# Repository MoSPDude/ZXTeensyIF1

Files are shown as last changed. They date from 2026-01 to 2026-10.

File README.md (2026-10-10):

# ZXTeensyIF1

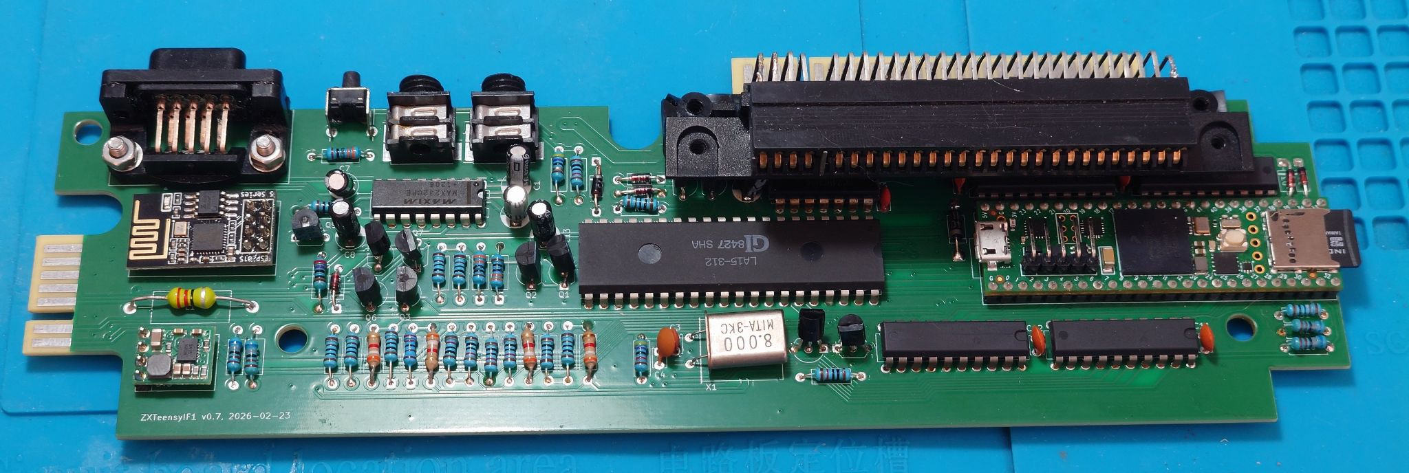
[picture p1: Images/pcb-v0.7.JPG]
Working PCB


A Teensy 4.1 powered DivMMC and ZX Interface 1 clone for the ZX Spectrum 48K/128K/+2 (Grey) machines,

* ZX Interface 1
    * Requires the 9V and 5V power rails
    * Uses a MAX232 for the RS232 level shifting, so no +12V or -12V required
    * Supports 16KB shadow soft ROM
        * eg. Ian Collier's modified Interface 1 ROM from https://ftp.nvg.ntnu.no/pub/sinclair/roms/imc-i1rom.zip
            * The [imc-i1.rom](Extras/imc-i1.rom) here contains a copy with the "Parallel Printer" modification disabled
* DivMMC with 512KB RAM
    * Supports accessing the main SD card, HDF and IMG images
    * Supports DivMMC AllRAM extension with write lock, automap disable and alternate MAPRAM page
        * https://github.com/mprato/DivMMC/blob/master/docs/Divmmc_allram_manual.txt
    * Large images over FAT32 file limit can be split into multiple files
        * eg. esximage.hdf, esximage.001, up to esximage.999
        * The maximum SD card image size is ~2TB
    * If you use images from https://esxdos.zxfiles.net/ - remember to hex edit "DMA=1" to "DMA=0"
* Multiface 128 emulation
    * NMI button and soft ROM
* ZX Interface 2 ROM cartridge emulation
    * It does not emulate the Joystick ports
* ZXC2 and ZXC3 with Flash ROM cartridge emulation
    * Implements ZXC2 ROM banking
    * Implements ZXC3 ROM banking with 128KB Flash ROM
    * Implements SPECTRA shadow ROM support
        * The ROM file needs to be named as "SPECTRA_\*.bin"
* Dandanator Mini with Flash ROM cartridge emulation
    * Implements slow pulsed banking, and fast command banking
    * Can load individual MLD files, or full 512KB generated ROM images
* ESP-01S module via TX8/RX8
    * Requires the 9V power rail for the 3.3V regulator
    * Available on ports 0x143B (5179) for RX and 0x133B (4923) for TX
    * https://www.specnext.com/the-next-on-the-network/
* USB mouse and gamepad Kempston interface
    * Not wired to the board - use a small lead that exits the case
    * eg. StarTech.com "6in USB 2.0 Cable - USB A Female to USB Motherboard 4 Pin Header F/F"
* RTC module from the Teensy
    * Accessed as a RTC-72421 on ports 0x7X3B
        * The time is only read or written when register 0xD sets HOLD to 1
    * Uses a minor bugfixed RTC.SYS from https://velesoft.speccy.cz/zx/rtcmodule/index.htm
        * Patched byte 6 from 0x0D to 0x7D
    * Not wired to the board - attach a coin cell battery to VBAT
        * See https://www.pjrc.com/store/teensy41.html#timing
* Single speed TZX and TAP playback
    * Playback locks the keyboard, as it overdrives the ULA
    * TAP loading is better done via the DivMMC
* Spectrum +3 uPD765a FDC emulation
    * Integrated lib765 v0.4.2 with additional bug fixes for "EXTENDED" disk loading
    * Requires Spectrum +2A/+3 soft ROM support (see below), or other compatible DOS
* Prism VTX5000 over ESP-01S
    * Creates a serial tunnel over WiFi to given URL
    * Default URL is '"glasstty.com",6502' - https://glasstty.com/telstar/
* Spectrum +3 and ZX LPRINT III Centronics printer
    * Writes output into a timestamped "printer-YYYYMMDD-HHMMSS.txt" file on SD card, adding a numeric suffix if that file already exists
* Soft ROM emulation
    * Override the internal Spectrum ROM with ROMs from SD card
    * Supports 16KB (Spectrum 48K), 32KB (Spectrum 128K/+2 (Grey)) and 64KB (Spectrum +2A/+3) ROMs
        * The +2A/+3 soft ROM support requires port decoding changes (see below)
    * Provides the peripheral ROMs
* Menu ROM derived from TomDDGs ZXPicoIF2Lite ROMExplorer
* Z80 snapshot loading from TomDDGs ZXPicoIF2Lite
    * Integrated "z80torom" for loading 'z80' and 'sna' files
* Save and restore states
    * Uses the Z80 snapshot loader to restore state on power-on
    * Hold the button to disable the power-on restore
* MDR microdrive loading with Paul Farrows SPECTRA Microdrive Emulator
    * http://www.fruitcake.plus.com/Sinclair/Interface2/Cartridges/Interface2_RC_New_Microdrive_Emulator.htm
    * Supports MDR images with up to 90KB of data
* Small WebDAV class 1 HTTP server for WiFi file access over ESP-01S
    * Accepts five clients, with SD card requests processed one at a time
    * Use WinSCP to send files, or HTTP PUT to send files eg. "curl -T FILENAME.ROM http://192.168.0.254/FILENAME.ROM"
        * Includes a simple LOCK/UNLOCK compatibility shim for Windows 11 support
    * Use web browser to list files, and download
* Nihirash's Network Manager for WiFi configuration
    * Small bugfix to clear the BASIC keypress on load
* Velesoft's RTC_SETUP for RTC configuration
    * Minor tweaks to preset the RTC port
* External ROM support
    * ZX Interface 1 edge connector supports other ROM based hardware
    * eg. Retroleum SMART card, real ZX Interface 2 hardware etc.

The ZX Interface 1 v2 ROM is included in compiled firmware, and as noted on other
sources "Amstrad have kindly given their permission for the redistribution
of their copyrighted material but retain that copyright"

The ZXTEENSY directory contains the peripheral ROM images - the exact redistribution
status of these is unknown, but they have been gathered from sources from the Internet,
and provided for convenience and safe-keeping.

This is a project that I started with a view of wanting a DivMMC clone that works with a
ZX Interface 1 attached to my ZX Max 128 - as I own a ZX Microdrive as well as a ZXPicoMD
(https://github.com/TomDDG/ZXPicoMD) ... and didn't want to keep disconnecting the ZX
Interface 1.

> [!WARNING]
> I created this for myself, and it is distributed in the hope that it will be useful,
> but WITHOUT ANY WARRANTY; without even the implied warranty of MERCHANTABILITY or
> FITNESS FOR A PARTICULAR PURPOSE.
>
> I take ZERO responsibility if it damages your hardware!

## Credits

Full credits to the following projects - this project gathers and integrates from
many various sources.

It borrows content, ideas and inspiration from,

* http://www.pjrc.com/teensy/
    * Teensyduino Core and SdFat libraries - provides all the Teensy 4.1 functionality
    * Reused parts of code for the RTC, SDHC and UART drivers
* https://github.com/SensoriumEmbedded/TeensyROM
    * Initial code and parts for the Teensy 4.1 firmware
* https://github.com/TomDDG/ZXPicoIF2Lite
    * ROM menu source code, Z80 snapshot loader, and the idea of a soft ROM
* http://www.fruitcake.plus.com/Sinclair/Interface2/Cartridges/Interface2_RC_Cartridges.htm
    * ZXC2 and ZXC3 banking, and Microdrive Emulator
* http://www.dandare.es/Proyectos_Dandare/ZX_Dandanator%21_Mini_EN.html
    * Dandantor Mini slow banking from PIC source code
    * Also, https://github.com/chernandezba/zesarux/tree/main/src/storage for fast banking
* https://github.com/nihirash/netman-zx
    * WiFi Network Manager for the ESP-01S
* https://velesoft.speccy.cz/zx/rtcmodule/index.htm
    * RTC_SETUP for the RTC module
    * RTC.SYS for EsxDOS
* https://www.seasip.info/Unix/LibDsk/
    * lib765 FDC controller library
* https://github.com/joepasquariello/FlasherX
    * Teensy 4.x OTA upgrade library
* https://github.com/liveboxandy/ZX-Interface-1-Recreated
    * Re-used the ZX Interface 1 board layout and schematic
* https://github.com/ZXSpectrumVault/rom-disassemblies
    * ZX Interface 1 v2 ROM disassembly
* https://spectrumcomputing.co.uk/pub/sinclair/technical-docs/ZXInterface1_Schematics.gif
    * ZX Interface 1 schematic
* https://spectrumcomputing.co.uk/pub/sinclair/technical-docs/PrismVTX5000Modem_Schematics-Interface.bmp
    * Prism VTX5000 schematic
* https://zxpress.ru/chapters_images/periferiya/periferiya-33.png
    * ZX LPRINT III schematic
* https://divide.speccy.cz/files/pgm_model.txt
    * DivIDE programming model
* https://www.thingiverse.com/thing:6500064
    * Also from TomDDG, a replacement ZX Interface 1 case

Without the above projects, this would not have been possible!

## Construction

[Construction details are here](PCB/README.md)

## SD Card Setup

* ZXTEENSY/
    * CONFIGS/
        * \<NAME\>.CFG (Saved configurations that appear as "NAME" in the Menu ROM for quick selection)
    * STATE/\<SLOT\>/ (Save slots 0-14; slot 15 is reserved)
        * STATE.Z80 (Z80 v3 snapshot for the save state)
        * SCREEN.SCR (6912-byte active Spectrum screen for load preview)
        * (Additional saved state files for the save slot)
    * MENU.ROM
    * MF128.ROM (MD5SUM: ca8c9d97c8aedd718d1081fad2e3af8d)
    * GENIE128.ROM (MD5SUM: b942f2e658d15da9747791a15a9a110d)
        * Genie 128K disassembler Multiface 128 RAM image
    * ESXMMC.BIN (MD5SUM: fa50b0258e52b8d72bd83cc2fb6e1013)
    * SPECTRA_IF1_ED2_ME_ROM_Formatted.bin (MD5SUM: 052ad91ee822604960e8ca8d32a3ddb9)
    * IF1.ROM (Optional)
    * VTX.ROM (MD5SUM: 12a62cb7ea7383f109c2711dfca99f5e)
    * LPRINT32.ROM (MD5SUM: e85f4ccb4cc80aaa81cceffb3e064bf7)
    * netman.z80 (WiFi Network Manager snapshot)
    * rtc_setup.z80 (RTC Setup snapshot)
    * ZXTEENSY.CFG (Current configuration from Menu ROM)
* ROMS/
    * (ZX Spectrum ROMs ending ".rom")
    * (ZXC2 ROMs ending ".bin")
    * (Other ROM files)
* (Other ESXDOS files)
* SYS/
    * [RTC.SYS](Extras/RTC.SYS) (Optional, for RTC access)
    * (Other ESXDOS files)
* ZXTEENSY.HEX (Optional, firmware update)

## Using the Menu ROM

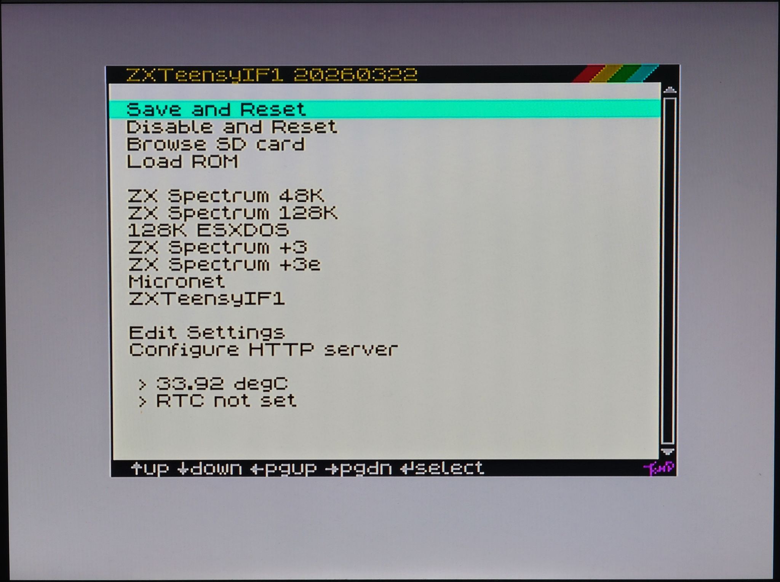
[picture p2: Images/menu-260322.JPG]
Menu 20260322


To load the Menu ROM, either,

* Use "Boot into Menu" to load on initial power on
* or, Hold the button, and Reset
* or, Hold Reset for longer than 5 seconds

Inside the Menu ROM you can,

* Restart with either the ZXTeensyIF1 enabled or disabled
    * Pressing Reset will also reset with the ZXTeensyIF1 enabled
* Browse the SD card to select files to load, or mount
    * Selecting known file extensions will either load or ask to mount
    * Selecting unknown file extensions will ask for an action
    * From the in-game browser, select a POK file and tick one or more trainers
      before selecting "Apply selected trainers"
* Browse the system Soft ROMs in the "ROMS/" directory to load, or set as Soft ROM
    * Double selecting a system Soft ROM will immediately reset into it
* Select a saved configuration to load
    * Double selecting a saved configuration will immediately reset into it
* Edit the configuration
    * Enable or disable the peripherals
    * Eject mounted disks by selecting them
    * Set to fetch time over the WiFI, and set the timezone
    * Load the RTC Setup or WiFi Network Manager snapshots
* Start or stop the HTTP server to transfer files over WiFi

To firmware update, place the ZXTEENSY.HEX file on the root of the SD card and
select the option from the Menu ROM - then wait for the Spectrum to reset
(!! It will take a minute !!).

In "Load ROMS", from the "ROMS/" directory,

| File extension | File type |
|---|---|
| .rom | System Soft ROM |
| .bin | ZXC2 cartridge |
| Other | ZX Interface 2 cartridge |

In "Browse SD card", in other directories,

| File extension | File type |
|---|---|
| .rom, .bin | ROM cartridge, or RAM image |
| .z80, .sna | Z80 snapshot |
| .hdf, .img | DivMMC SD card |
| .dsk | Spectrum +3 disk |
| .mdr | ZX Microdrive cartridge |
| .tap, .tzx | Audio cassette |
| .pok | POK trainers (in-game browser only) |
| Other | The menu will ask for an action |

POK trainers are applied by saving a temporary state to reserved slot 15,
patching the selected RAM banks, and immediately restoring that state. POK
trainers that require a prompted value (`256`) are not supported and cannot be
enabled.

### Preparing the SD Card

ESXDOS has trouble loading if it is not "early" on the SD card,

* Format the SD card with FAT32
* Extract ESXDOS on computer, and transfer all directories and ESXMMC.BIN to the SD card
* Transfer the "/ZXTEENSY" directory, with ROMs and CONFIGS
* Create system "/ROMS" directory, and add other ROMs
* Add any other files

#### Fun stuff !!

The https://esxdos.zxfiles.net/ site has a HDF image that can be split using the script
in the tools folder, to use as an SD card image.

 * You will just need to hex edit part of the image file to change the setting "DMA=1" to "DMA=0" !!
 * You can browse the image with 7-Zip to extract the "GAMES.ROM" folder for access to the ROM games

The [MOONR.zip](Extras/MOONR.zip) is a compiled version of Moon Rabbit v1.6 from
https://github.com/nihirash/moon-rabbit-zx with MB03+ serial for the WiFi, but
with the regular Spectrum screen and without the proxy ("-DMB03 -DZXSCR").

The [imc-i1.rom](Extras/imc-i1.rom) is Ian Collier's modified Interface 1 ROM -
place it as "ZXTEENSY/IF1.ROM" to use instead of the internal compiled v2 ROM.

Z80 BBC BASIC for the ZX Spectrum can be downloaded from https://mdfs.net/Software/Spectrum/BBCBasic/ .
Use the 32K combined BBC BASIC and ZX BASIC ROM - placing it in the ROMS folder, and
selecting it as the system ROM.

## Building the firmware

* Setup the Arduino IDE 2.3.6 for the Teensy 4.1
    * "Teensy (for Arduino IDE 2.0.4 or later)" v1.60.0
* Open ZXTeensyIF1\ZXTeensyIF1.ino
* Set Board to Teensy 4.1
* Set Optimize to "Smallest Code with LTO"
* Set CPU Speed to "720 MHz (overclock)"
* Verify and Upload

## Prism VTX5000 support

The VTX5000 over ESP-01S uses the ESP8266 in UART-WiFi passthrough mode after establishing
a connection to a URL over TCP. If the VTX.ROM is provided, then it will load after reset.
The default URL is the TELSTAR Viewdata service at https://glasstty.com/telstar/ .

To access TELSTAR,
 * Press CAPS SHIFT + ENTER to open the menu
 * Press 0 to "Log ON or OFF"
 * Press 1 for "Manual Log ON"
 * Enter the ID "\*\*\*\*\*\*\*\*\*\*" ie. 10 asterixes
 * Read the welcome message, and press ENTER as the "#" key

To navigate, either press numbers to select items, or enter pages in the form of "*800#" :-
 * SYMBOL SHIFT is the "*" key
 * ENTER is the "#" key

## WebDAV class 1 support

The HTTP server accepts five connections. Requests are processed one at a time because the
ESP-01S UART and SD card are shared; an inactive connection remains buffered by the ESP-01S.

Windows 11 sends LOCK and UNLOCK commands when copying files to the server, though not
supported in WebDAV class 1. The server just acknowledges the exclusive file locks, creates
the empty target required by a LOCK on a new path, and accepts refresh and unlock requests -
purely as a compatibility shim. An interrupted transfer can leave its empty target file behind.

WinSCP seems to work fine - you may need to change the preferences to ensure only
a single upload connection.

OpenAI Codex helped to provide the additional WebDAV class 1 implementation over
just the basic HTTP PUT and GET that I'd implemented.

## +2A/+3 soft ROM on Spectrum 128K/+2 (Grey) machines

Spectrum 128K, +2 (Grey) and similar machines (eg. ZX Max 128 Issue 3) require a modification to
support the +2A/+3 soft ROM.

Without it, accesses to the Secondary Memory Control register (0x1FFD) also affect the original
Memory Control register (0x7FFD) due to the partial decoding. (More info at
https://worldofspectrum.org/faq/reference/128kreference.htm)

### Spectrum 128K/+2 (Grey) Memory Control port decoding

The BANK decoding is performed by a PAL10H8 chip, which can be swapped for a GAL16V8 to apply
the "Unrainer/IN 7FFD" fix - see https://spectrumforeveryone.com/technical/applying-the-unrainerin-7ffd-fix-to-128grey-2-machines/ and
Velesoft https://velesoft.speccy.cz/zx/umbrella/umbrella.htm for the original article and files.

Unrainer fixed GAL16V8s with socket and wire can be bought from the Retroleum shop at
https://retroleum.co.uk/.

But, by adding a "BANK = ... & ZA14" term, then the GAL will support the decoding
required for the +2A/+3 soft ROM.

I've placed the updated files in the GAL folder.

* Remove IC29 (Spectrum 128K) / IC7 (Grey +2) - and replace with a socket
    * *Take care of the orientation of the socket!* (The Grey +2 has it pointing downwards)
* On the underside, add a wire from CPU pin 28 to the GAL socket pin 11
* Program the GAL16V8 with GALNEW2A.JED, and fit into socket
    * Again, taking care with the orientation!

### ZX Max 128 Issue 3 Memory Control port decoding

The modification is shown at
https://github.com/DonSuperfo/ZX-Max-128/blob/main/Issue%203/Modify%20for%20%2B3%20ROM.pdf,

* Replace R12 with a 1N4148 diode, with cathode to U9 pin 9
    * So it is the same orientation as D1 that is next to it
* Add a 1N4148 diode from U6 pin 12 to the cathode of the new diode in place of R12
    * This connects "nA14"
* Add a 10K resistor from ground (eg. U9 pin 8) to the cathode of the new diode in place of R12
    * This is the replacement position for R12

## 3rd party Xbox One USB gamepads

You will need to find and add the USB PID:VID code for the controller to the USBHost_t36
library.

In the case of my "8BitDo M30 Wired Controller for Xbox One", under Windows 11
Device Manager, it was the "Xbox Peripherals > Xbox Gaming Device" *NOT* the
(virtual) HID device. Right click the device, select Properties, then Details and
select "Hardware IDs" to find it listed as "USB\VID_2DC8&PID_200A&..."

Once found, add the USB PID:VID code to %LOCALAPPDATA%\Arduino15\packages\teensy\hardware\avr\1.60.0\libraries\USBHost_t36\joystick.cpp,
under JoystickController::pid_vid_mapping ,

* 8BitDo M30 Wired Controller for Xbox One :- \{ 0x2dc8, 0x200a, XBOXONE, false \}

## ROM paging and banking

ROMs are paged in a priority order - if more than one ROM is paged, the highest active entry wins.
When that ROM pages out, it falls back to the next highest active entry. The base
Spectrum ROMs are mutually exclusive, and selected by the 128K/+2A/+3 Memory Control
registers - while add-on ROMs can sit above them until they are paged out.

The following ROMs are provided by the Teensy, listed in priority order,

| Peripheral / ROM | Pages in from | Pages out from | Banking notes |
| --- | --- | --- | --- |
| Spectrum ROM 0 | On reset, or I/O port 0x7FFD bit 4 = 0, and I/O port 0x1FFD bit 2 = 0 | Replaced by another Spectrum ROM | 48K BASIC ROM, or 128K/+2 Editor ROM slot |
| Spectrum ROM 1 | I/O port 0x7FFD bit 4 = 1, and I/O port 0x1FFD bit 2 = 0 | Replaced by another Spectrum ROM | 128K/+2 BASIC ROM, or +2A/+3 Syntax ROM slot |
| Spectrum ROM 2 | I/O port 0x7FFD bit 4 = 0, and I/O port 0x1FFD bit 2 = 1 | Replaced by another Spectrum ROM | +2A/+3 +3DOS ROM slot |
| Spectrum ROM 3 | I/O port 0x7FFD bit 4 = 1, and I/O port 0x1FFD bit 2 = 1 | Replaced by another Spectrum ROM | +2A/+3 BASIC ROM slot |
| Interface 1 | Post-M1 access to address 0x0008 or 0x1708 from Spectrum ROM 0, 1 or 3, when Interface 1 is enabled and DivMMC is not | Post-M1 access to address 0x0700 | Emulates Interface 1 ROM paging while the Teensy inhibits the physical Interface 1 ULA I/O decode when DivMMC is active. |
| Multiface 128 | Multiface NMI path at address 0x0066/0x0067, or read from I/O port 0xXXBF | Read from I/O port 0xXX3F; write to I/O port 0xXX3F also disables Multiface mode | Higher priority than Interface 1, so Interface 1 may be marked paged underneath it and then become visible after Multiface pages out. |
| DivMMC | M1 access to addresses 0x3Dxx, post-M1 access to addresses 0x0000, 0x0008, 0x0038, 0x04C6 or 0x0562 from Spectrum ROM 0, 1 or 3; DivMMC NMI at address 0x0066; I/O port 0xXXE3 with CONMEM/automap active; or AllRAM enabled | Post-M1 access to addresses 0x1FF8-0x1FFF unless MAPRAM or AllRAM is active; or I/O port 0xXXE3 when CONMEM, automap and AllRAM are clear | I/O port 0xXXE3 also selects the DivMMC RAM bank. Bit 7 is CONMEM, bit 6 latches MAPRAM, and the low bits select internal or extended RAM. MAPRAM serves RAM bank 3 (or the alternate AllRAM page) instead of the ROM when CONMEM is clear. |
| LPRINT III | Read from I/O port 0xXXFB | Read from I/O port 0xXX7B | Printer data/strobe writes use I/O ports 0xXX7B and 0xXXFB; ROM paging itself is read-port driven. |
| VTX5000 modem | VTX5000 register write to I/O port 0xXXFF with bit 5 clear | VTX5000 register write to I/O port 0xXXFF with bit 5 set | The first register write after reset is ignored. |
| ZXC2/ZXC3 cartridge | ZXC2/ZXC3 address-banking access in addresses 0x3FC0-0x3FFF, or post-M1 access to address 0x0008/0x1708 when used as Shadow ROM | ZXC2/ZXC3 address-banking access in addresses 0x3FC0-0x3FFF, or post-M1 access to address 0x0700 when used as Shadow ROM | For ZXC2, address bits 0-3 select the 16KB bank and bit 4 pages in/out. ZXC3 uses bits 0-2 for the bank and bit 3 to enter flash-write handling. Bit 5 locks further ZXC2/ZXC3 paging. |
| Dandanator/MLD cartridge | Dandanator/MLD slow-pulse or fast command bank select | Dandanator/MLD page-out command | Commands 1-32 select slots, command 33 pages out, command 34 pages out and locks, and command 40 performs the fast bank/control command. |
| Snapshot/state loader | Snapshot/state loader start | Access to address 0x3FFF advances loader banks; the final access pages out | Used for generated snapshot/state loader ROMs. |
| Menu ROM | Menu NMI target at address 0x0066, from any current ROM | Post-M1 access to address 0x003B | Highest priority ROM. I/O port 0xXXBF selects the active menu RAM page, and I/O port 0xXXEB is used for menu commands and selections. |

## I/O port mapping

The following ports are decoded by the Teensy,

| Port | R/W | Function | Comments |
| ---- | --- | --- | --- |
| 0xXX1F | R | Kempston joystick | |
| 0x0F3B | W | DivMMC AllRAM control register | |
| 0x133B | R | UART status | |
| 0x133B | W | UART TX data | |
| 0x143B | R | UART RX data | |
| 0x143B | W | UART baud register | |
| 0x7N3B | R/W | DivMMC RTC registers 0 - 15 | N is the register address |
| 0xXX3F | R | Multiface 128 page out | Returns bit 7 as the Current Screen |
| 0xXX3F | W | Multiface 128 disable | |
| 0xXX7B | R | LPRINT III page out | Returns status |
| 0xXX7B | W | LPRINT III data with strobe | |
| 0xXX7F | R/W | VTX5000 data | |
| 0xXXBF | R | Multiface 128 page in | Returns bit 7 as the Current Screen |
| 0xXXBF | W | Multiface 128 NMI clear | Menu ROM RAM banking |
| 0xFADF | R | Kempston mouse buttons | |
| 0xFBDF | R | Kempston mouse X axis | |
| 0xFFDF | R | Kempston mouse Y axis | |
| 0xXXE3 | W | DivMMC control register | |
| 0xXXE7 | W | DivMMC SPI select | |
| 0xXXEB | R/W | DivMMC SPI data | Menu ROM read command, write selected option |
| 0xXXFB | R | LPRINT III page in | Returns status |
| 0xXXFB | W | LPRINT III data, clear strobe | |
| 0x0FFD | R | +3 Centronics busy status | |
| 0x0FFD (0b0000XXXX_XXXXXX0X) | W | +3 Centronics data | |
| 0x1FFD (0b0001XXXX_XXXXXX0X) | W | +2A / +3 Secondary Memory Control | ROM paging, +3 FDC motor and +3 Centronics strobe |
| 0x2FFD | R | +3 FDC status register | |
| 0x3FFD | R | +3 FDC data | |
| 0x3FFD (0b0011XXXX_XXXXXX0X) | W | +3 FDC data | |
| 0x7FFD (0b01XXXXXX_XXXXXX0X) | W | 128K Memory Control | Current Screen, and ROM paging |
| 0xXXFE | R | Spectrum ULA | Drives EAR input for tape |
| 0xXXFF | R/W | VTX5000 register | Ignore first write access, controls ROM paging |

The following ports are decoded by the Interface 1 ULA when not inhibited by the Teensy,

| Port | R/W | Function | Comments |
| ---- | --- | --- | --- |
| 0xXXE7 (0bXXX00XXX) | R/W | Interface 1 microdrive data | Halts Z80 on read |
| 0xXXEF (0bXXX01XXX) | R/W | Interface 1 control register | |
| 0xXXF7 (0bXXX10XXX) | R/W | Interface 1 RS232/network data | |

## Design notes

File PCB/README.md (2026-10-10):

# ZXTeensyIF1 Construction

## Loading the KiCad project

The PCB folder contains a KiCad 9.0.2 project, based on liveboxandy "ZX Interface 1 Recreated" KiCad
7 project. Without that project, I'd have had to spend considerable time getting the board outline
correct, and aligning the sockets etc.

It uses,

* https://github.com/XenGi/teensy_library as teensy_library-master
* https://github.com/XenGi/teensy.pretty as teensy.pretty-master
    * Set XGENGI_TEENSY_LIBRARY path in Symbol Libraries etc.
* https://github.com/sparkfun/SparkFun-KiCad-Libraries
    * Set SPARKFUN_KICAD_LIBRARY path in Symbol Libraries etc.
* https://github.com/nosuz/kicad-symbols-footprints
    * Place as ./nosuz-kicad-symbols-footprints in the project directory

Freerouting (https://github.com/freerouting/freerouting) was used to perform the initial routing,
especially with getting the address and data lines out to the level shifters and the Interface 1
ULA.

## Bill of Materials

| Reference | Qty | Value | Comments |
| --- | --- | --- | --- |
| C1, C2, C7, C8 | 4 | 1uF | Use 0.1uF if U8 is MAX232A, or 0.33uF if MAX3232 |
| C3 | 1 | 100pF | |
| C4 | 1 | 22pF | |
| C5 | 1 | 47nF | |
| C6, C13 | 2 | 47uF 16V | |
| C9, C10, C11, C12 | 4 | 100nF | |
| D1, D2, D3, D9, D11 | 5 | 1N4148 | |
| D4 | 1 | 1N4001 | or 1N400X equivalent |
| D8 | 1 | BZX79CV4V3 | or ZPD4V3 equivalent |
| J1 | 1 | ESP-01S | Optional, for WiFi |
| J3 | 1 | Polou D24V5F3 | Optional, fit if ESP-01S is fitted |
| L1 | 1 | 22uH 0.41A | |
| Q1, Q2 | 2 | BC213C | |
| Q3, Q6, Q9 | 3 | BC184C | |
| Q4, Q5, Q7, Q8 | 4 | PN2222A | |
| Q10, Q11 | 2 | ZTX313 | |
| R1, R3, R5, R11, R12, R14, R24, R25, R31 | 9 | 1K0 | |
| R2, R10, R17, R18 | 4 | 6K8 | |
| R4, R6, R8, R13 | 4 | 3K9 | |
| R7 | 1 | 47R | |
| R9, R16, R21, R26, R27, R33, R36 | 7 | 10K | |
| R15 | 1 | 2K2 | |
| R22, R23, R34 | 3 | 330R | |
| R30 | 1 | 270R | |
| R35 | 1 | 47K | |
| SK1 | 1 | DE9_Receptacle | |
| SK2, SK3 | 2 | 3.5mm Mono Switched Socket | with break contact eg. Cliff CL1384 |
| SK5 | 1 | ZX Spectrum edge connector | Can be difficult - see notes |
| SW1 | 1 | PTH_RA_h7.5mm | 6 x 6mm x 8mm Right Angle |
| U1 | 1 | LA15-302 | ZX Interface 1 ULA - can be LA15-312 or vLA1 |
| U2 | 1 | Teensy4.1 | Teensy 4.1 No Ethernet |
| U3, U5, U6, U7 | 4 | SN74LVC245AN | |
| U4 | 1 | 74HCU04 | |
| U8 | 1 | MAX232 | Alternative is MAX232A or MAX3232 |
| X1 | 1 | 8Mhz crystal | |

## Notes

In my build, the 74HCU04, BZX79CV4V3, 8 MHz crystal, 3K9 resistors, inductor
and all connectors came from a donor ZX Interface 1 board. The ULA was a LA15-312
that I had bought to fix the donor originally, before I had the idea to create
this. Removing the ZX Interface 1 edge connector that goes to the ZX Spectrum was
an immense pain - even with gentle heat, I managed to deform and melt the plastic
riser block... it was as though it was glued to the board as well as screwed.

But for my second board, having found another donor that had a ULA that melted the
case, simply removing the screws holding the edge connector riser and de-soldering
was enough - it was removed very easily! The ULA for this board is a replacement
vLA1, that worked after some firmware fixes. Only the connectors and BZX79CV4V3
had been re-used from this donor board.

## Hardware revisions

* v0.7b PCB
    * *NOT MANUFACTURED*
    * Changed C13 to 47uF
        * The Teensy was not always resetting correctly after power on, so increased this
    * Moved C6 slightly
        * The ZX Spectrum edge connector plastic riser block had a support that just caught the top of it!
        * Hopefully, this slight adjustment will solve that
* v0.7 PCB prototype
    * PCBs have been returned from PCBWay
    * Moved the ROMCS and DataDir output to pins 36 and 37, to free up pins 34 and 35
    * Added an ESP-01S header, and header for 3.3V regulator (eg. Pololu D24V5F3)
        * The ESP-01S can take over 300mA, so requires a separate regulator
        * The Pololu D24V5F3 is a 3.3V 500mA regulator module, available from The Pi Hut
        * I had to re-organise the left side of the board to make room
    * Connected RX8 pin 34 and TX8 pin 35, to the ESP-01S header
* v0.2 PCB prototype
    * First PCBs made, and tested
        * Microdrive, RS232, ZX Net and nROMCS on external edge connector working
        * Firmware updated for new pin layout - soft ROM all working
    * Need to revise some footprints
    * The PCBs had silkscreen that stated v0.1
* v0.1 veroboard prototype (not uploaded)
    * Prototype to test the initial idea
    * Teensy 4.1 and level shifters on Veroboard
        * Soft ROM and Multiface 128 behaviour working
    * Modded ZX Interface 1 to add "nIORQ inhibit" (see below)

## DivMMC and ZX Interface 1 support

Technically, the DivMMC and ZX Interface 1 cannot be active simultaneously. The DivMMC ports and
ZX Interface 1 I/O ports clash directly. (More info at below)

To overcome this, the Teensy drives the nIORQ of the Interface 1 ULA high when the DivMMC is
active. Also, only A3 and A4 have been wired to the Interface 1 ULA, as required for the port
decoding - which helped with the PCB routing. The Teensy provides all the ROM facilities for
the Interface 1 behaviour.

## Updating the ESP-01S

The ESP-01S needs to be running the Non-OS AT firmware that can be downloaded from
https://github.com/espressif/ESP8266_NONOS_SDK .

The current version is SDK v3.0.6 with AT version 1.7.6.0,
```
AT version:1.7.6.0(Jan 24 2022 08:56:02)
SDK version:3.0.6-dev(072755c)
compile time:Jun 17 2024 07:38:00
Bin version(Wroom 02):1.7.6
```

The ZXTeensyIF1 cannot update the firmware, so it needs to be done with a suitable
connection to a computer - such as https://thepihut.com/products/esp-flasher and
the VSCode Serial Monitor.

To find your current version, issue the command "AT+GWR" at baud rate 115200,
1 stop bit, no parity, DTR set, RTS set, with CRLF line endings.

I used esptool-v4.8.1-win64 and the following command to flash, with my USB serial
adapter on COM3,
```
./esptool.exe -p COM3 write_flash --flash_size 1MB 0x0 boot_v1.7.bin 0x01000 user1.1024.new.2.bin 0xfb000 blank.bin 0xfc000 esp_init_data_default_v08.bin 0xfe000 blank.bin 0x7e000 blank.bin
```

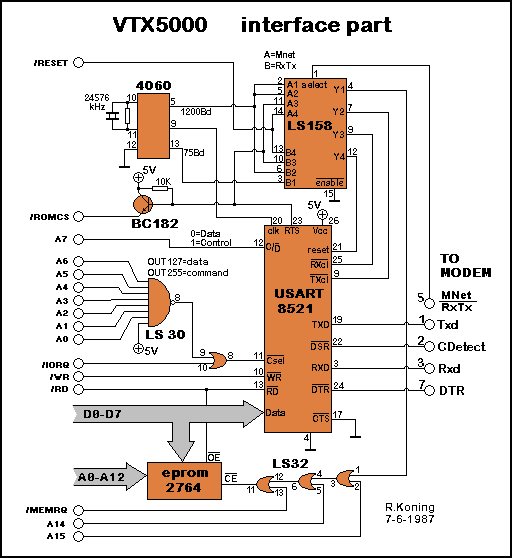
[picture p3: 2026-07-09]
Images/PrismVTX5000Modem_Schematics-Interface.bmp

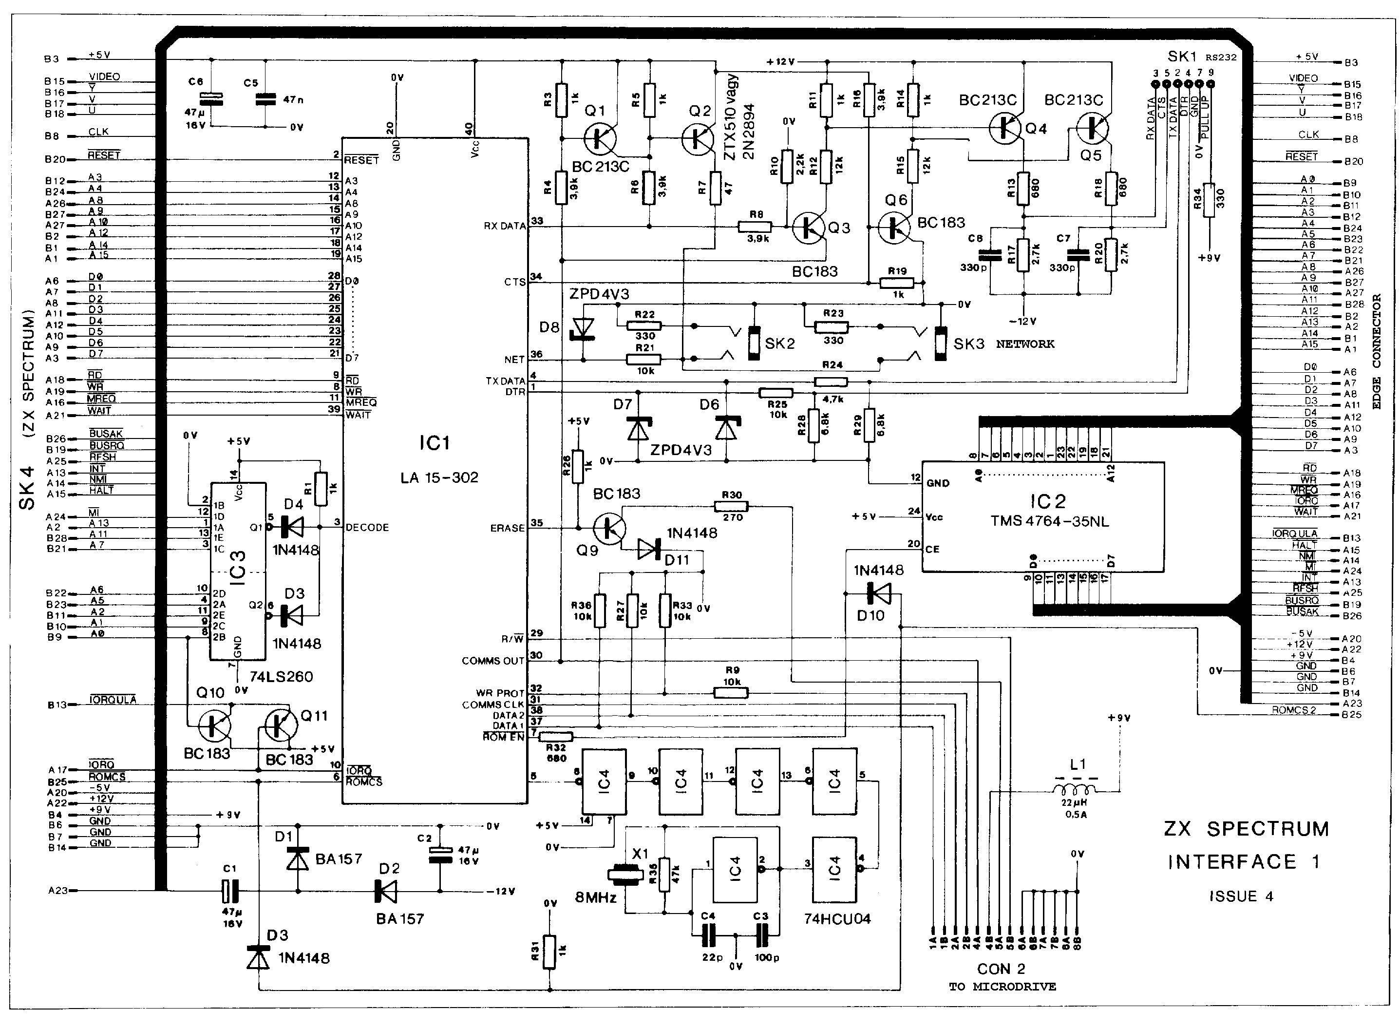
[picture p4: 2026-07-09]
Images/ZXInterface1_Schematics.gif

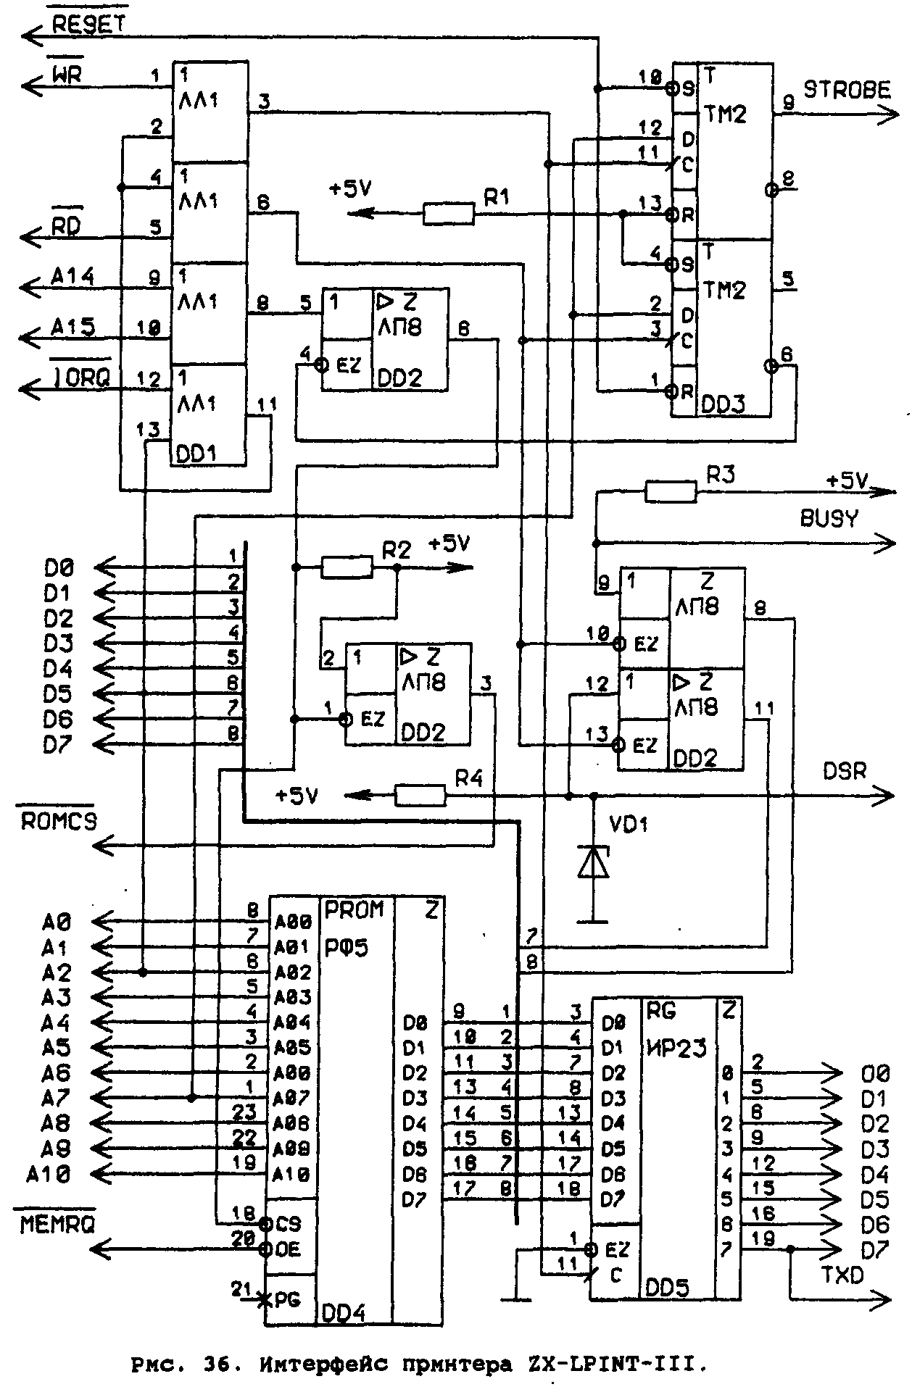
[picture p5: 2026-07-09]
Images/periferiya-33.png

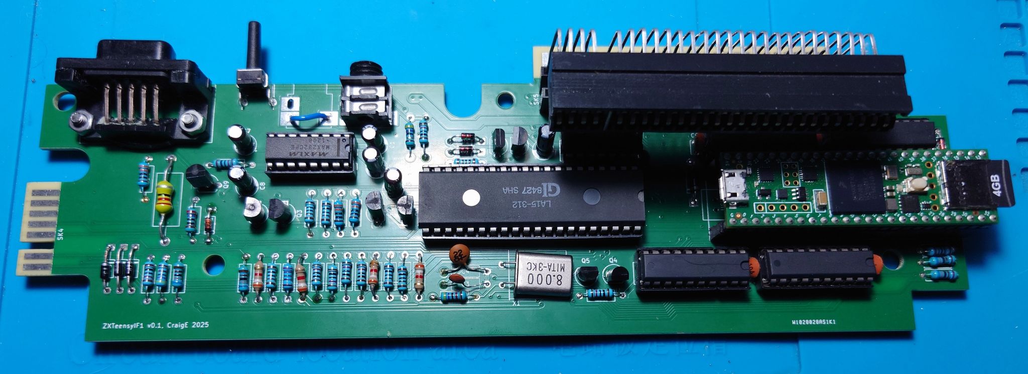
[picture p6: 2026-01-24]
Images/pcb-v0.2.JPG

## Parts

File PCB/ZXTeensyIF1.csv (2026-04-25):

Reference | Qty | Value | DNP | Exclude from BOM | Exclude from Board | Footprint | Datasheet
C1,C2,C7,C8 | 4 | 1uF |  |  |  | Capacitor_THT:CP_Radial_D5.0mm_P2.50mm | ~
C3 | 1 | 100pF |  |  |  | Capacitor_THT:C_Disc_D3.4mm_W2.1mm_P2.50mm | ~
C4 | 1 | 22pF |  |  |  | Capacitor_THT:C_Disc_D3.4mm_W2.1mm_P2.50mm | ~
C5 | 1 | 47nF |  |  |  | Capacitor_THT:C_Disc_D3.4mm_W2.1mm_P2.50mm | ~
C6,C13 | 2 | 47uF 16V |  |  |  | Capacitor_THT:CP_Radial_D5.0mm_P2.50mm | ~
C9,C10,C11,C12 | 4 | 100nF |  |  |  | Capacitor_THT:C_Disc_D3.4mm_W2.1mm_P2.50mm | ~
D1,D2,D3,D9,D11 | 5 | 1N4148 |  |  |  | Diode_THT:D_DO-35_SOD27_P7.62mm_Horizontal | https://assets.nexperia.com/documents/data-sheet/1N4148_1N4448.pdf
D4 | 1 | 1N4004 |  |  |  | Diode_THT:D_DO-41_SOD81_P10.16mm_Horizontal | http://www.vishay.com/docs/88503/1n4001.pdf
D8 | 1 | BZX79CV4V3 |  |  |  | Diode_THT:D_DO-35_SOD27_P10.16mm_Horizontal | ~
J1 | 1 | ESP-01S-Header |  |  |  | Connector_PinSocket_2.54mm:PinSocket_2x04_P2.54mm_Vertical | ~
J3 | 1 | Polou D24V5F3 |  |  |  | Connector_PinSocket_2.54mm:PinSocket_1x04_P2.54mm_Vertical | ~
L1 | 1 | 22uH 0.41A |  |  |  | Inductor_THT:L_Axial_L12.8mm_D5.8mm_P20.32mm_Horizontal_Fastron_HBCC | ~
Q1,Q2 | 2 | BC213C |  |  |  | Package_TO_SOT_THT:TO-92L_Inline_Wide | ~
Q3,Q6,Q9 | 3 | BC184C |  |  |  | Package_TO_SOT_THT:TO-92L_Inline_Wide | ~
Q4,Q5,Q7,Q8 | 4 | PN2222A |  |  |  | Package_TO_SOT_THT:TO-92_Inline_Wide | https://www.onsemi.com/pub/Collateral/PN2222-D.PDF
Q10,Q11 | 2 | ZTX313 |  |  |  | Package_TO_SOT_THT:TO-92L_Inline_Wide | ~
R1,R31 | 2 | 1K0 |  |  |  | Resistor_THT:R_Axial_DIN0207_L6.3mm_D2.5mm_P7.62mm_Horizontal | ~
R2,R10 | 2 | 6K8 |  |  |  | Resistor_THT:R_Axial_DIN0207_L6.3mm_D2.5mm_P7.62mm_Horizontal | ~
R3,R5,R11,R12,R14,R24,R25 | 7 | 1K0 |  |  |  | Resistor_THT:R_Axial_DIN0207_L6.3mm_D2.5mm_P10.16mm_Horizontal | ~
R4,R6,R8,R13 | 4 | 3K9 |  |  |  | Resistor_THT:R_Axial_DIN0207_L6.3mm_D2.5mm_P10.16mm_Horizontal | ~
R7 | 1 | 47R |  |  |  | Resistor_THT:R_Axial_DIN0207_L6.3mm_D2.5mm_P10.16mm_Horizontal | ~
R9,R16,R21,R26,R27,R33,R36 | 7 | 10K |  |  |  | Resistor_THT:R_Axial_DIN0207_L6.3mm_D2.5mm_P10.16mm_Horizontal | ~
R15 | 1 | 2K2 |  |  |  | Resistor_THT:R_Axial_DIN0207_L6.3mm_D2.5mm_P10.16mm_Horizontal | ~
R17,R18 | 2 | 6K8 |  |  |  | Resistor_THT:R_Axial_DIN0207_L6.3mm_D2.5mm_P10.16mm_Horizontal | ~
R22,R23,R34 | 3 | 330R |  |  |  | Resistor_THT:R_Axial_DIN0207_L6.3mm_D2.5mm_P10.16mm_Horizontal | ~
R30 | 1 | 270R |  |  |  | Resistor_THT:R_Axial_DIN0207_L6.3mm_D2.5mm_P10.16mm_Horizontal | ~
R35 | 1 | 47K |  |  |  | Resistor_THT:R_Axial_DIN0207_L6.3mm_D2.5mm_P7.62mm_Horizontal | ~
SK1 | 1 | DE9_Receptacle |  |  |  | Connector_Dsub:DSUB-9_Socket_Horizontal_P2.77x2.84mm_EdgePinOffset14.56mm_Housed_MountingHolesOffset15.98mm | ~
SK2,SK3 | 2 | Network |  |  |  | ZX Spectrum 3.5mm:ZX Spectrum 3.5mm Skt | ~
SK4 | 1 | Microdrive |  |  |  | ZX Bits:ZX_MD_Edge_Connector | ~
SK5 | 1 | ZX Spectrum |  |  |  | ZX Bits:Spectrum_Edge_Connector
SK6 | 1 | ZX Expansion |  |  |  | ZX Bits:ZX_Bus_Edge_Connector
SW1 | 1 | PTH_RA_h7.5mm |  |  |  | SparkFun-Switch:Push_PTH_RA_8-020_h7.5mm | ~
U1 | 1 | LA15-302 |  |  |  | Package_DIP:DIP-40_W15.24mm | LA 15-302 Custom ULA
U2 | 1 | Teensy4.1 |  |  |  | teensy.pretty-master:Teensy41
U3,U5,U6,U7 | 4 | SN74LVC245APW |  |  |  | Package_DIP:DIP-20_W7.62mm | https://www.ti.com/lit/ds/scas218x/scas218x.pdf
U4 | 1 | 74HC04 |  |  |  | Package_DIP:DIP-14_W7.62mm | https://assets.nexperia.com/documents/data-sheet/74HC_HCT04.pdf
U8 | 1 | MAX232 |  |  |  | Package_DIP:DIP-16_W7.62mm | http://www.ti.com/lit/ds/symlink/max232.pdf
X1 | 1 | 8Mhz |  |  |  | Crystal:Crystal_HC18-U_Horizontal | ~

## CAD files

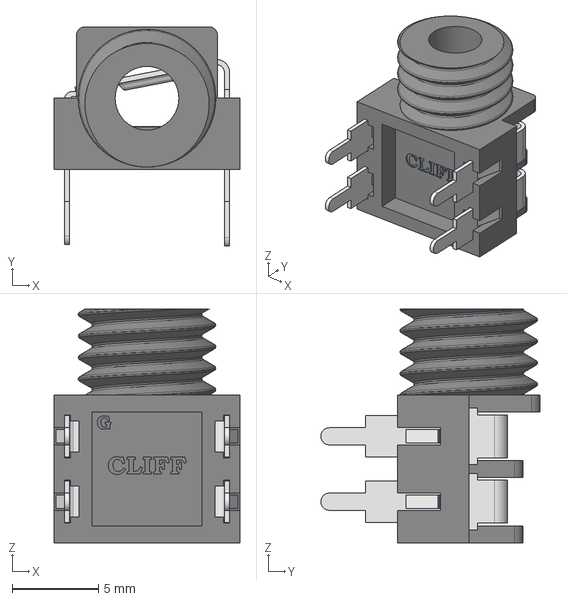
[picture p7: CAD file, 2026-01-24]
PCB/FCR1281 S6A 6mm.stp
10.8 x 12.8 x 13.6 mm

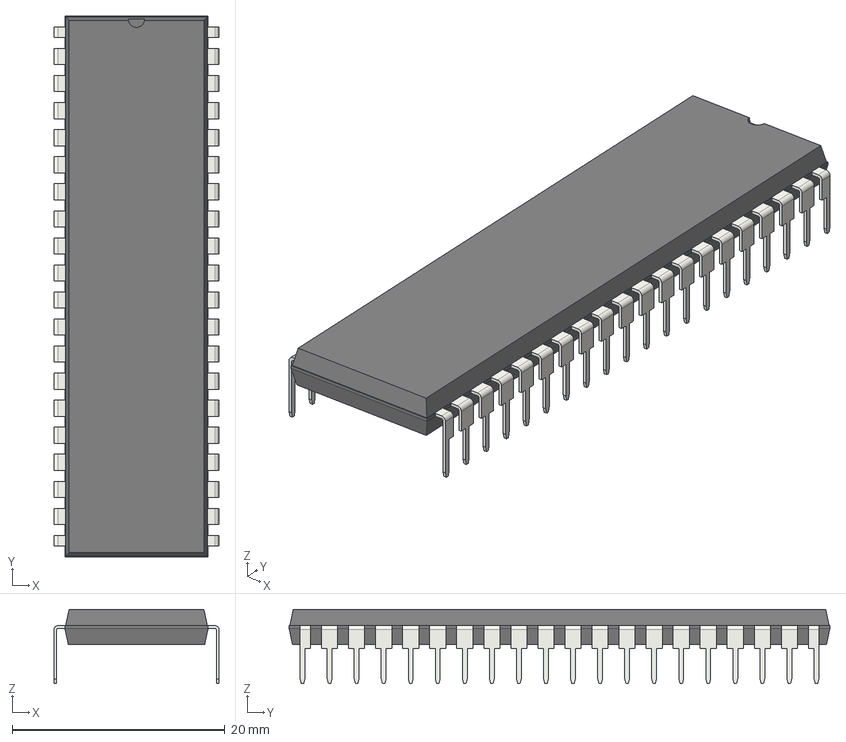
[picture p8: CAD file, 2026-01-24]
PCB/DIP-40_W15.24mm.step
15.5 x 50.8 x 6.98 mm

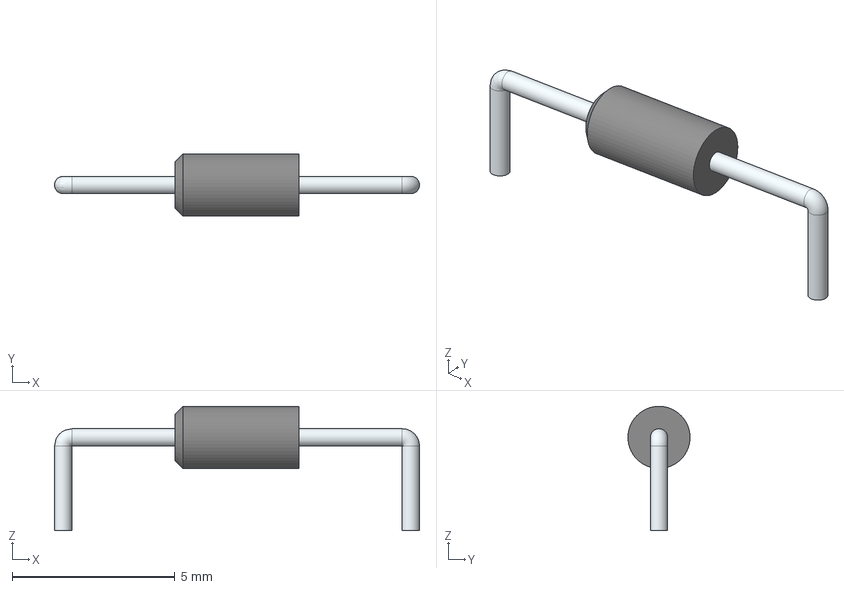
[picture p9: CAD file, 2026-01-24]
PCB/1N4148.stp
11.2 x 1.91 x 3.82 mm

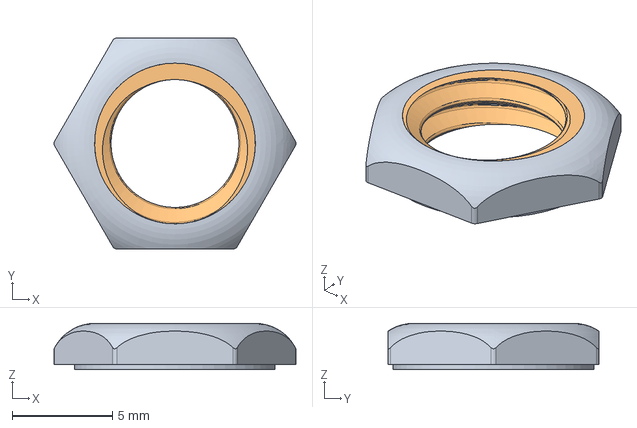
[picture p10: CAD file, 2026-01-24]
PCB/CL1434 S6 nut.stp
12.0 x 10.5 x 2.30 mm

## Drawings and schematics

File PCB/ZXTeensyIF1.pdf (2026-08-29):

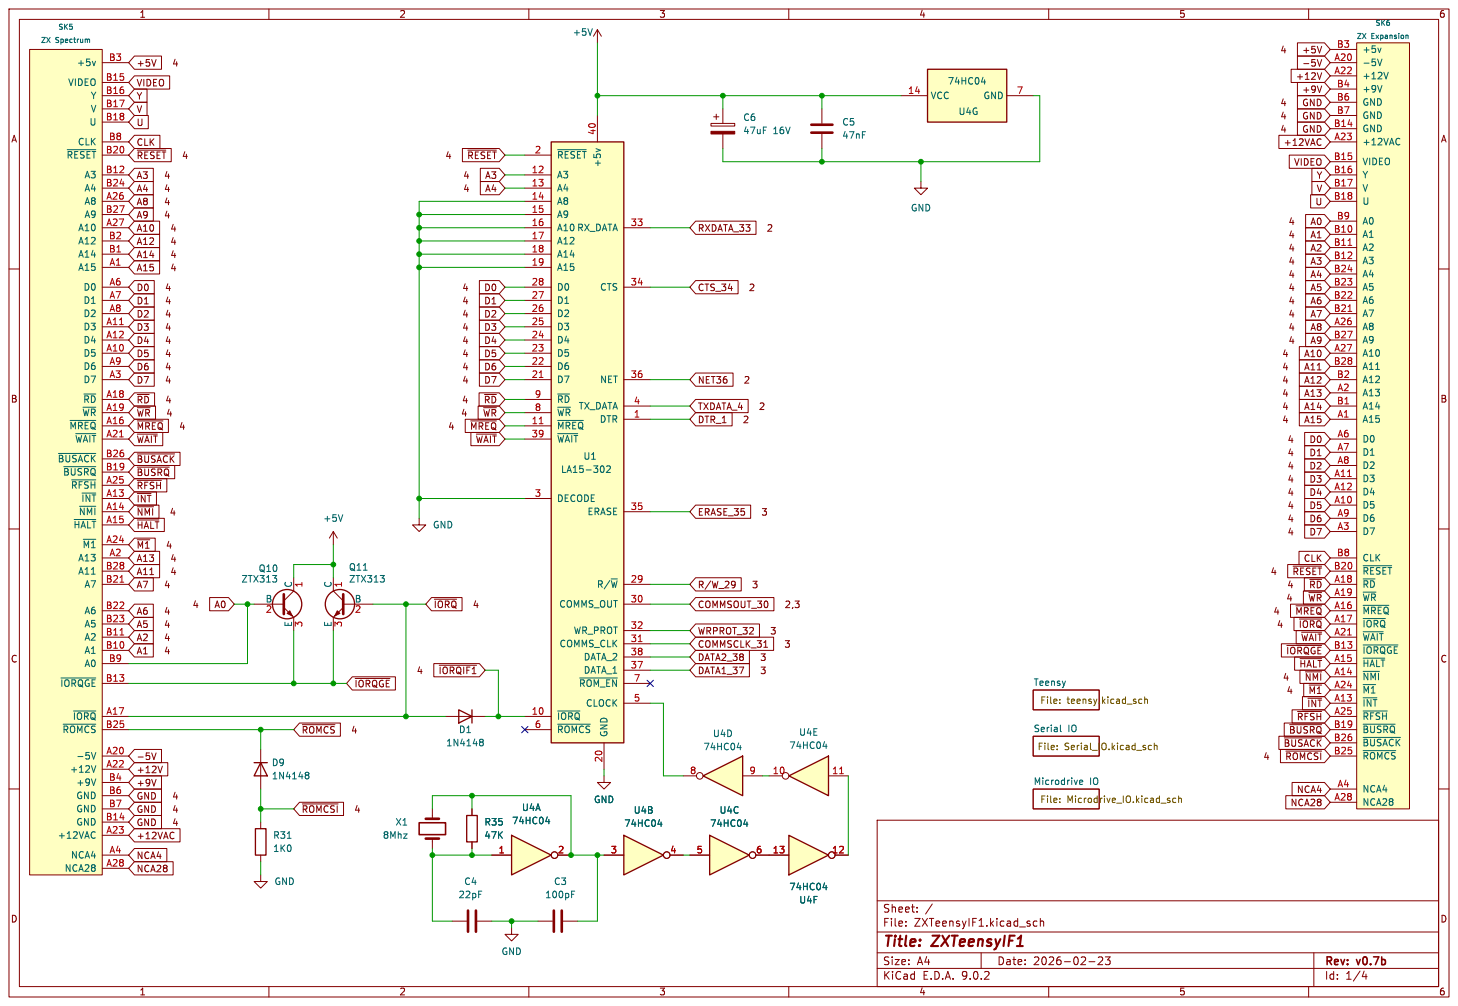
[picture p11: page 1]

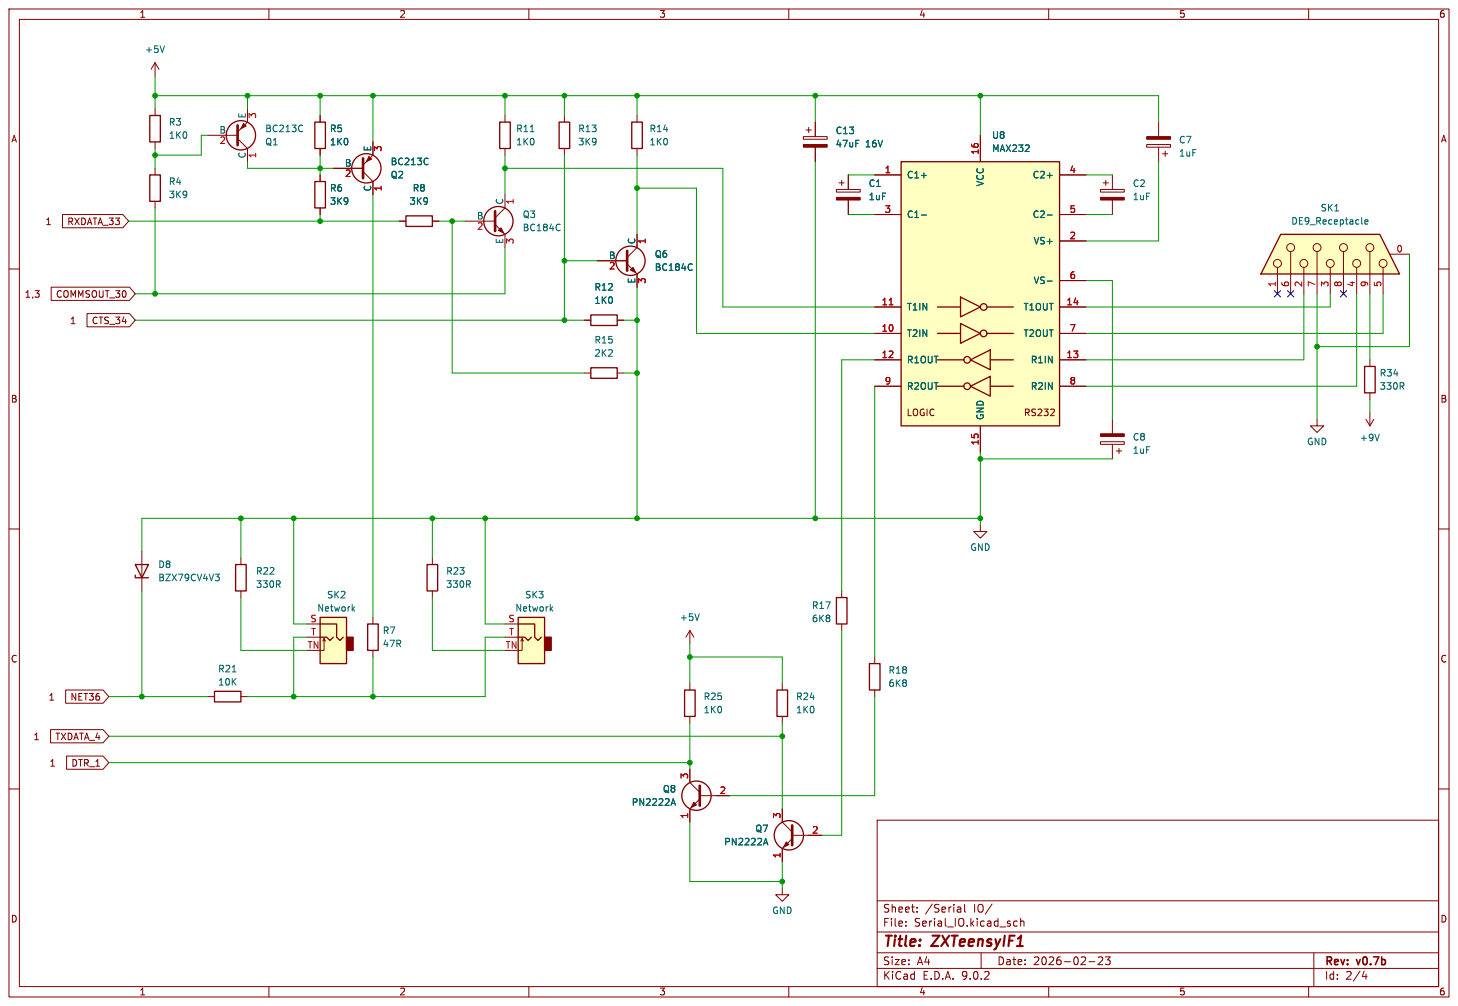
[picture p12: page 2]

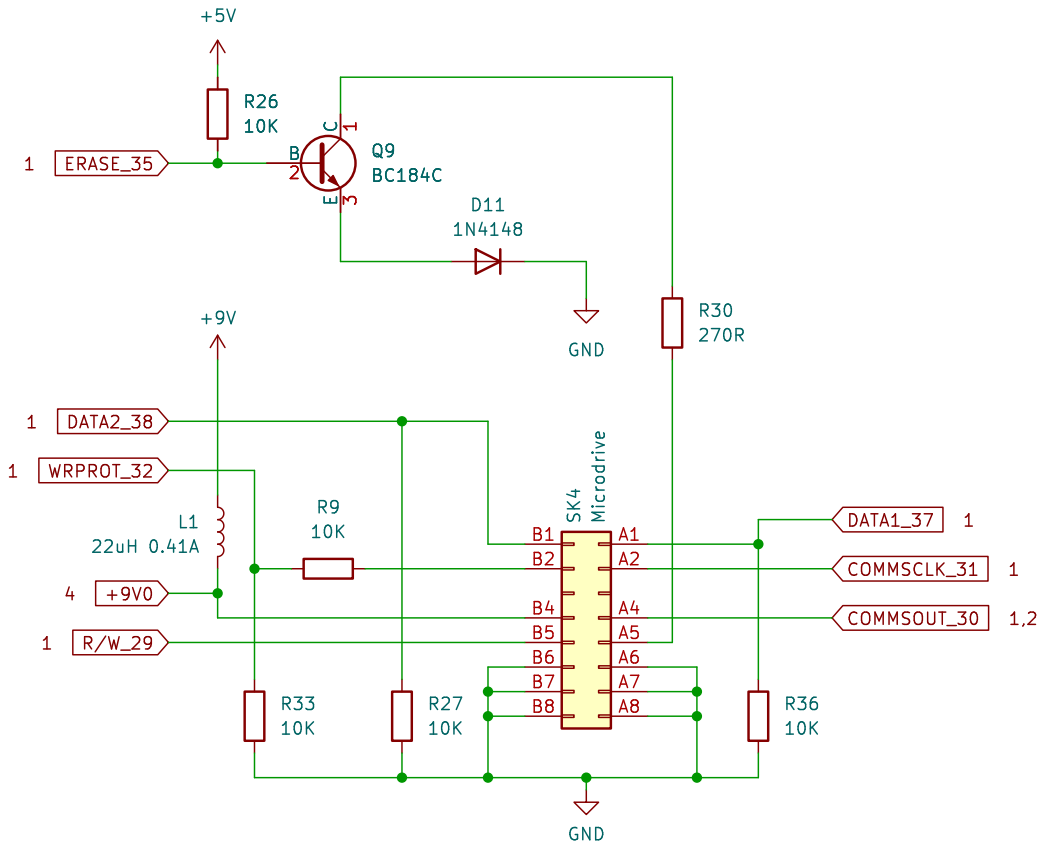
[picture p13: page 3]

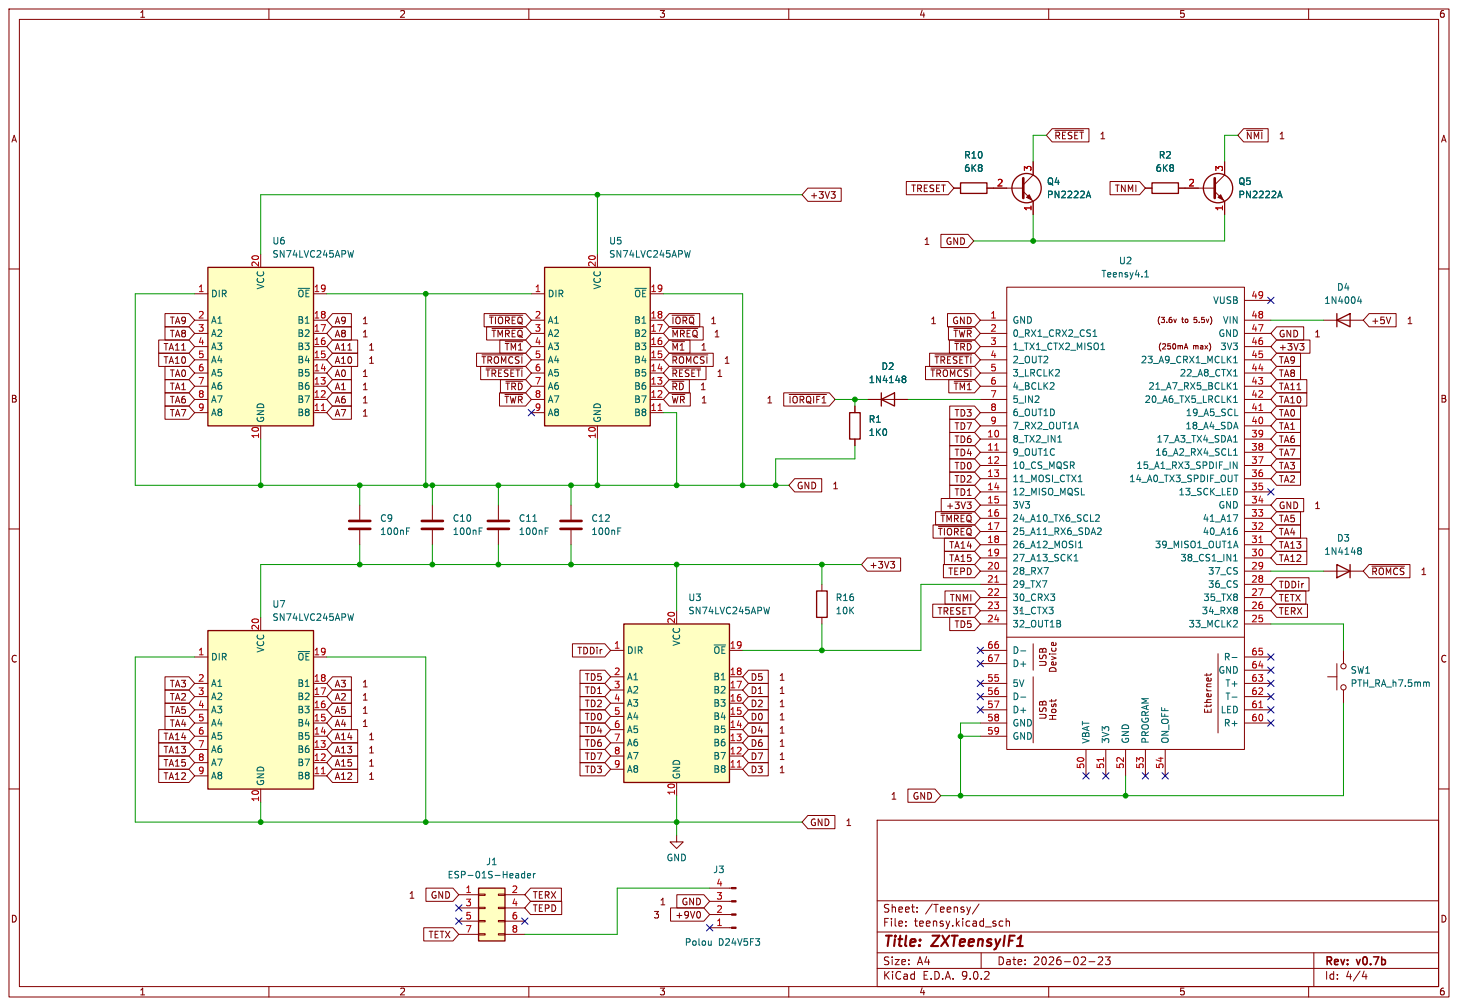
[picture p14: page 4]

~{IORQ} 1 ~{M1} 1 ~{MREQ} 1 ~{RD} 1 ~{ROMCSI} 1 ~{RESET} 1 ~{WR} 1 ~{TRD}
~{TMREQ}
~{TROMCSI}

File: teensy.kicad_sch Sheet: /Teensy/ C12

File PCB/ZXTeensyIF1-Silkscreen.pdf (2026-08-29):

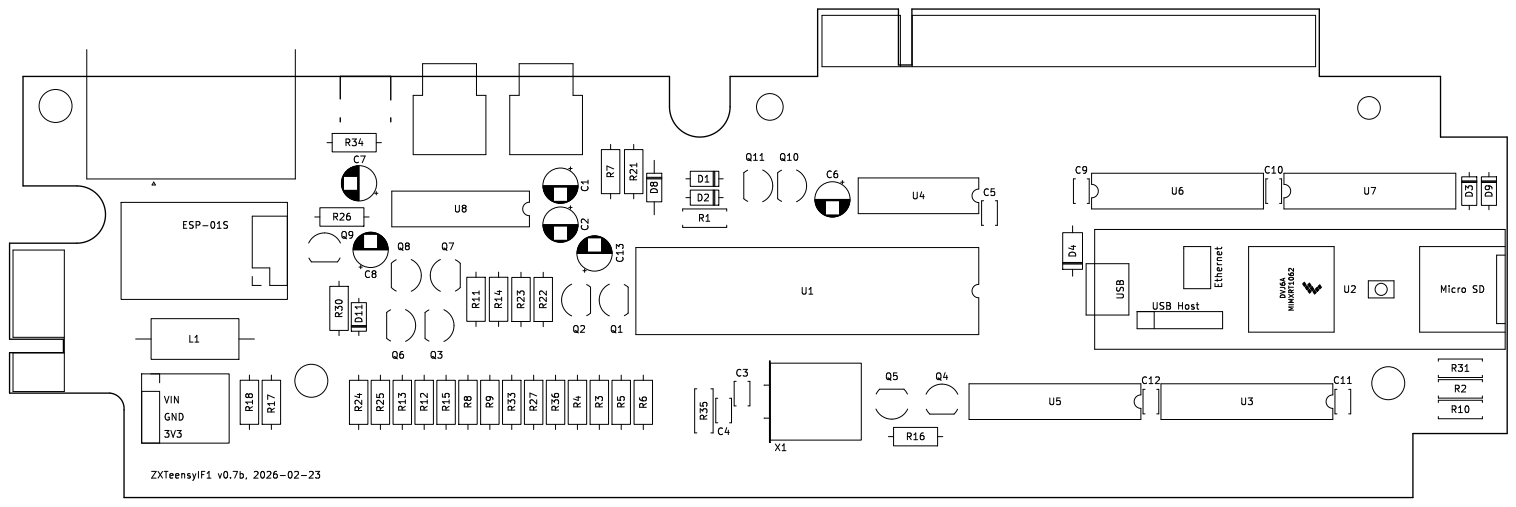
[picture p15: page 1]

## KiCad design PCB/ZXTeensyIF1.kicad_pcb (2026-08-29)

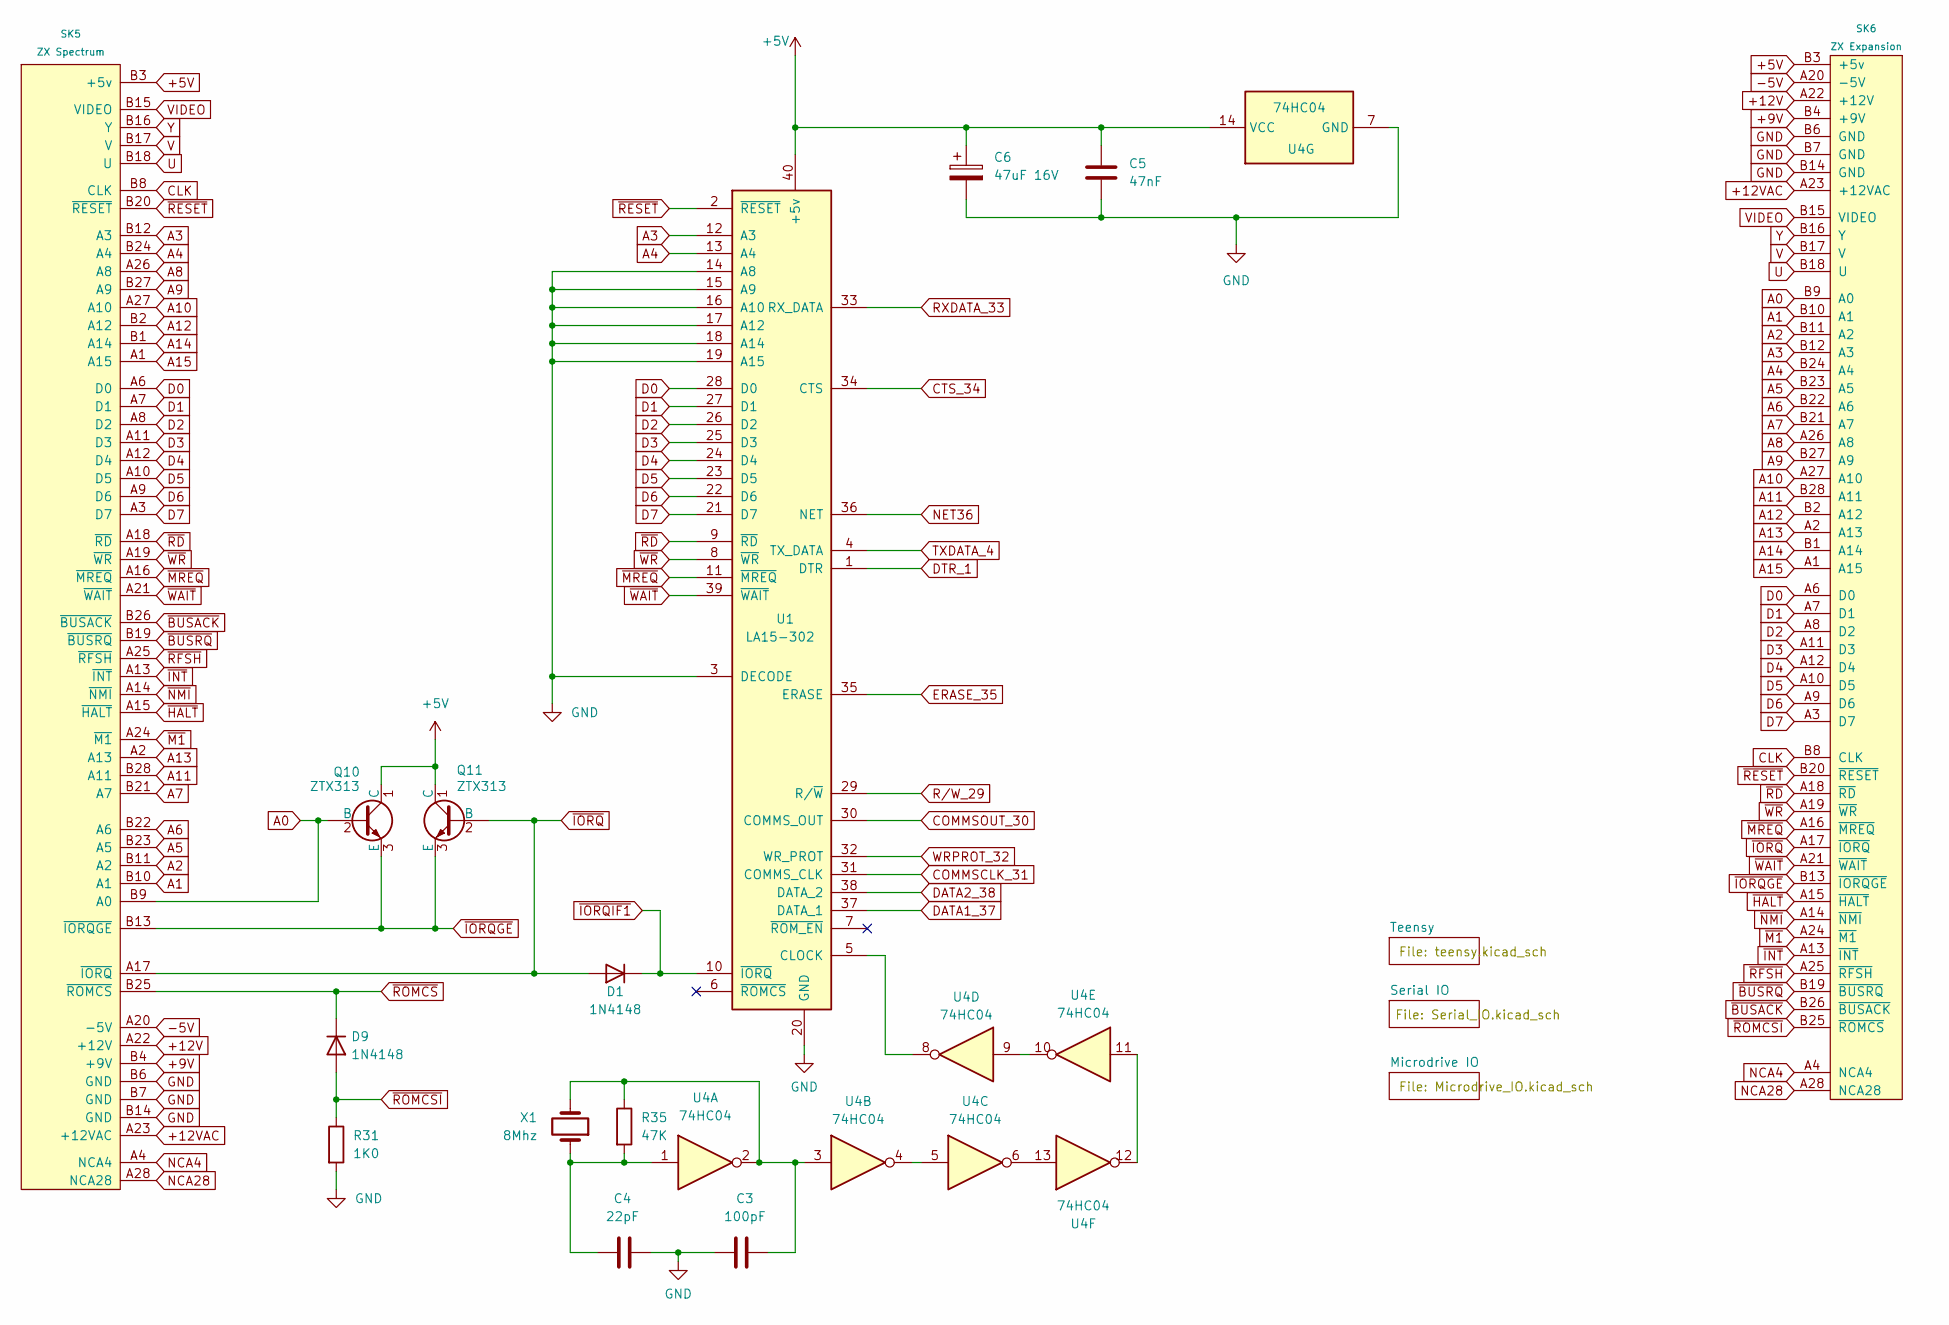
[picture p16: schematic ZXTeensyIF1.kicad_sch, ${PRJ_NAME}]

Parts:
C3: 100pF; C_Disc_D3.4mm_W2.1mm_P2.50mm
C4: 22pF; C_Disc_D3.4mm_W2.1mm_P2.50mm
C5: 47nF; C_Disc_D3.4mm_W2.1mm_P2.50mm
C6: 47uF 16V; CP_Radial_D5.0mm_P2.50mm
D1, D9: 1N4148; D_DO-35_SOD27_P7.62mm_Horizontal
Q10, Q11: ZTX313; TO-92L_Inline_Wide
R31: 1K0; R_Axial_DIN0207_L6.3mm_D2.5mm_P7.62mm_Horizontal
R35: 47K; R_Axial_DIN0207_L6.3mm_D2.5mm_P7.62mm_Horizontal
SK5: ZX Spectrum; Spectrum_Edge_Connector
SK6: ZX Expansion; ZX_Bus_Edge_Connector
U1: LA15-302; DIP-40_W15.24mm
U4: 74HC04; DIP-14_W7.62mm
X1: 8Mhz; Crystal_HC18-U_Horizontal

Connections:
+5V: C5.1, C6.1, Q10.1 (C), Q11.1 (C), SK5.B3 (+5v), SK6.B3 (+5v), U1.40 (+5v), U4.14 (VCC); also elsewhere on the board
+9V: SK5.B4 (+9V), SK6.B4 (+9V); also elsewhere on the board
+12V: SK5.A22 (+12V), SK6.A22 (+12V)
+12VAC: SK5.A23 (+12VAC), SK6.A23 (+12VAC)
-5V: SK5.A20 (-5V), SK6.A20 (-5V)
A0: Q10.2 (B), SK5.B9 (A0), SK6.B9 (A0); also elsewhere on the board
A1: SK5.B10 (A1), SK6.B10 (A1); also elsewhere on the board
A2: SK5.B11 (A2), SK6.B11 (A2); also elsewhere on the board
A3: SK5.B12 (A3), SK6.B12 (A3), U1.12 (A3); also elsewhere on the board
A4: SK5.B24 (A4), SK6.B24 (A4), U1.13 (A4); also elsewhere on the board
A5: SK5.B23 (A5), SK6.B23 (A5); also elsewhere on the board
A6: SK5.B22 (A6), SK6.B22 (A6); also elsewhere on the board
A7: SK5.B21 (A7), SK6.B21 (A7); also elsewhere on the board
A8: SK5.A26 (A8), SK6.A26 (A8); also elsewhere on the board
A9: SK5.B27 (A9), SK6.B27 (A9); also elsewhere on the board
A10: SK5.A27 (A10), SK6.A27 (A10); also elsewhere on the board
A11: SK5.B28 (A11), SK6.B28 (A11); also elsewhere on the board
A12: SK5.B2 (A12), SK6.B2 (A12); also elsewhere on the board
A13: SK5.A2 (A13), SK6.A2 (A13); also elsewhere on the board
A14: SK5.B1 (A14), SK6.B1 (A14); also elsewhere on the board
A15: SK5.A1 (A15), SK6.A1 (A15); also elsewhere on the board
CLK: SK5.B8 (CLK), SK6.B8 (CLK)
COMMSCLK_31: U1.31 (COMMS_CLK); also elsewhere on the board
COMMSOUT_30: U1.30 (COMMS_OUT); also elsewhere on the board
CTS_34: U1.34 (CTS); also elsewhere on the board
D0: SK5.A6 (D0), SK6.A6 (D0), U1.28 (D0); also elsewhere on the board
D1: SK5.A7 (D1), SK6.A7 (D1), U1.27 (D1); also elsewhere on the board
D2: SK5.A8 (D2), SK6.A8 (D2), U1.26 (D2); also elsewhere on the board
D3: SK5.A11 (D3), SK6.A11 (D3), U1.25 (D3); also elsewhere on the board
D4: SK5.A12 (D4), SK6.A12 (D4), U1.24 (D4); also elsewhere on the board
D5: SK5.A10 (D5), SK6.A10 (D5), U1.23 (D5); also elsewhere on the board
D6: SK5.A9 (D6), SK6.A9 (D6), U1.22 (D6); also elsewhere on the board
D7: SK5.A3 (D7), SK6.A3 (D7), U1.21 (D7); also elsewhere on the board
DATA1_37: U1.37 (DATA_1); also elsewhere on the board
DATA2_38: U1.38 (DATA_2); also elsewhere on the board
DTR_1: U1.1 (DTR); also elsewhere on the board
ERASE_35: U1.35 (ERASE); also elsewhere on the board
GND: C3.2, C4.1, C5.2, C6.2, R31.2, SK5.B6 (GND), SK5.B7 (GND), SK5.B14 (GND), SK6.B6 (GND), SK6.B7 (GND), SK6.B14 (GND), U1.3 (DECODE), U1.14 (A8), U1.15 (A9), U1.16 (A10), U1.17 (A12), U1.18 (A14), U1.19 (A15), U1.20 (GND), U4.7 (GND); also elsewhere on the board
NCA4: SK5.A4 (NCA4), SK6.A4 (NCA4)
NCA28: SK5.A28 (NCA28), SK6.A28 (NCA28)
NET36: U1.36 (NET); also elsewhere on the board
unnamed: C3.1, R35.1, U4.2, U4.3, X1.2
unnamed: C4.2, R35.2, U4.1, X1.1
unnamed: U1.5 (CLOCK), U4.8
unnamed: U4.4, U4.5
unnamed: U4.9, U4.10
unnamed: U4.11, U4.12
unnamed: U4.6, U4.13
RXDATA_33: U1.33 (RX_DATA); also elsewhere on the board
R/W_29: U1.29 (R/~W); also elsewhere on the board
TXDATA_4: U1.4 (TX_DATA); also elsewhere on the board
U: SK5.B18 (U), SK6.B18 (U)
V: SK5.B17 (V), SK6.B17 (V)
VIDEO: SK5.B15 (VIDEO), SK6.B15 (VIDEO)
WRPROT_32: U1.32 (WR_PROT); also elsewhere on the board
Y: SK5.B16 (Y), SK6.B16 (Y)
~BUSACK: SK5.B26 (~BUSACK), SK6.B26 (~BUSACK)
~BUSRQ: SK5.B19 (~BUSRQ), SK6.B19 (~BUSRQ)
~HALT: SK5.A15 (~HALT), SK6.A15 (~HALT)
~INT: SK5.A13 (~INT), SK6.A13 (~INT)
~IORQGE: Q10.3 (E), Q11.3 (E), SK5.B13 (~IORQGE), SK6.B13 (~IORQGE)
~IORQIF1: D1.1 (K), U1.10 (~IORQ); also elsewhere on the board
~IORQ: D1.2 (A), Q11.2 (B), SK5.A17 (~IORQ), SK6.A17 (~IORQ); also elsewhere on the board
~M1: SK5.A24 (~M1), SK6.A24 (~M1); also elsewhere on the board
~MREQ: SK5.A16 (~MREQ), SK6.A16 (~MREQ), U1.11 (~MREQ); also elsewhere on the board
~NMI: SK5.A14 (~NMI), SK6.A14 (~NMI); also elsewhere on the board
~RD: SK5.A18 (~RD), SK6.A18 (~RD), U1.9 (~RD); also elsewhere on the board
~RESET: SK5.B20 (~RESET), SK6.B20 (~RESET), U1.2 (~RESET); also elsewhere on the board
~RFSH: SK5.A25 (~RFSH), SK6.A25 (~RFSH)
~ROMCSI: D9.2 (A), R31.1, SK6.B25 (~ROMCS); also elsewhere on the board
~ROMCS: D9.1 (K), SK5.B25 (~ROMCS); also elsewhere on the board
~WAIT: SK5.A21 (~WAIT), SK6.A21 (~WAIT), U1.39 (~WAIT)
~WR: SK5.A19 (~WR), SK6.A19 (~WR), U1.8 (~WR); also elsewhere on the board

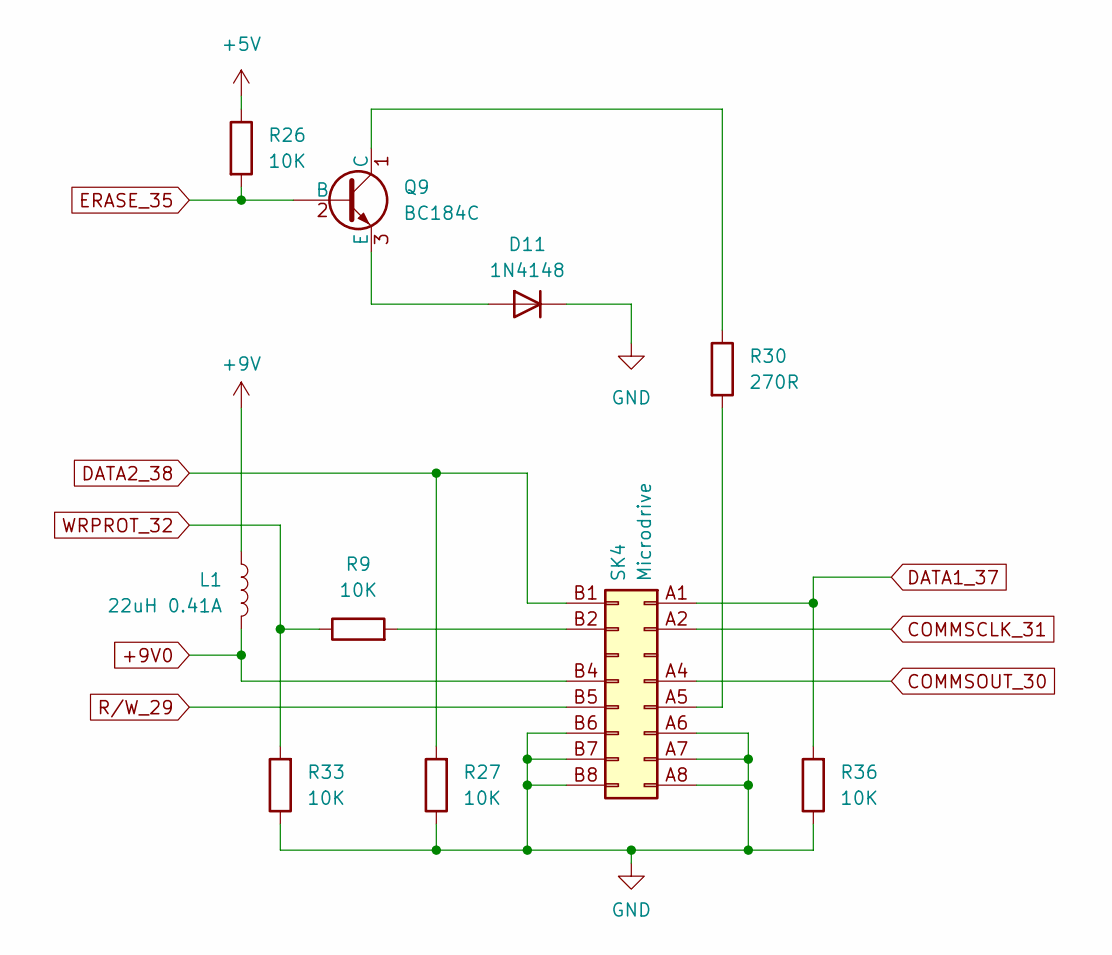
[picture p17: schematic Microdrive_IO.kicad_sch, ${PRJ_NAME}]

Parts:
D11: 1N4148; D_DO-35_SOD27_P7.62mm_Horizontal
L1: 22uH 0.41A; L_Axial_L12.8mm_D5.8mm_P20.32mm_Horizontal_Fastron_HBCC
Q9: BC184C; TO-92L_Inline_Wide
R9, R26, R27, R33, R36: 10K; R_Axial_DIN0207_L6.3mm_D2.5mm_P10.16mm_Horizontal
R30: 270R; R_Axial_DIN0207_L6.3mm_D2.5mm_P10.16mm_Horizontal
SK4: Microdrive; ZX_MD_Edge_Connector

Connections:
+5V: R26.1; also elsewhere on the board
+9V: L1.1; also elsewhere on the board
+9V0: L1.2, SK4.B4; also elsewhere on the board
COMMSCLK_31: SK4.A2; also elsewhere on the board
COMMSOUT_30: SK4.A4; also elsewhere on the board
DATA1_37: R36.2, SK4.A1; also elsewhere on the board
DATA2_38: R27.2, SK4.B1; also elsewhere on the board
ERASE_35: Q9.2 (B), R26.2; also elsewhere on the board
GND: D11.1 (K), R27.1, R33.1, R36.1, SK4.A6, SK4.A7, SK4.A8, SK4.B6, SK4.B7, SK4.B8; also elsewhere on the board
unnamed: D11.2 (A), Q9.3 (E)
unnamed: Q9.1 (C), R30.1
unnamed: R30.2, SK4.A5
unnamed: R9.2, SK4.B2
R/W_29: SK4.B5; also elsewhere on the board
WRPROT_32: R9.1, R33.2; also elsewhere on the board

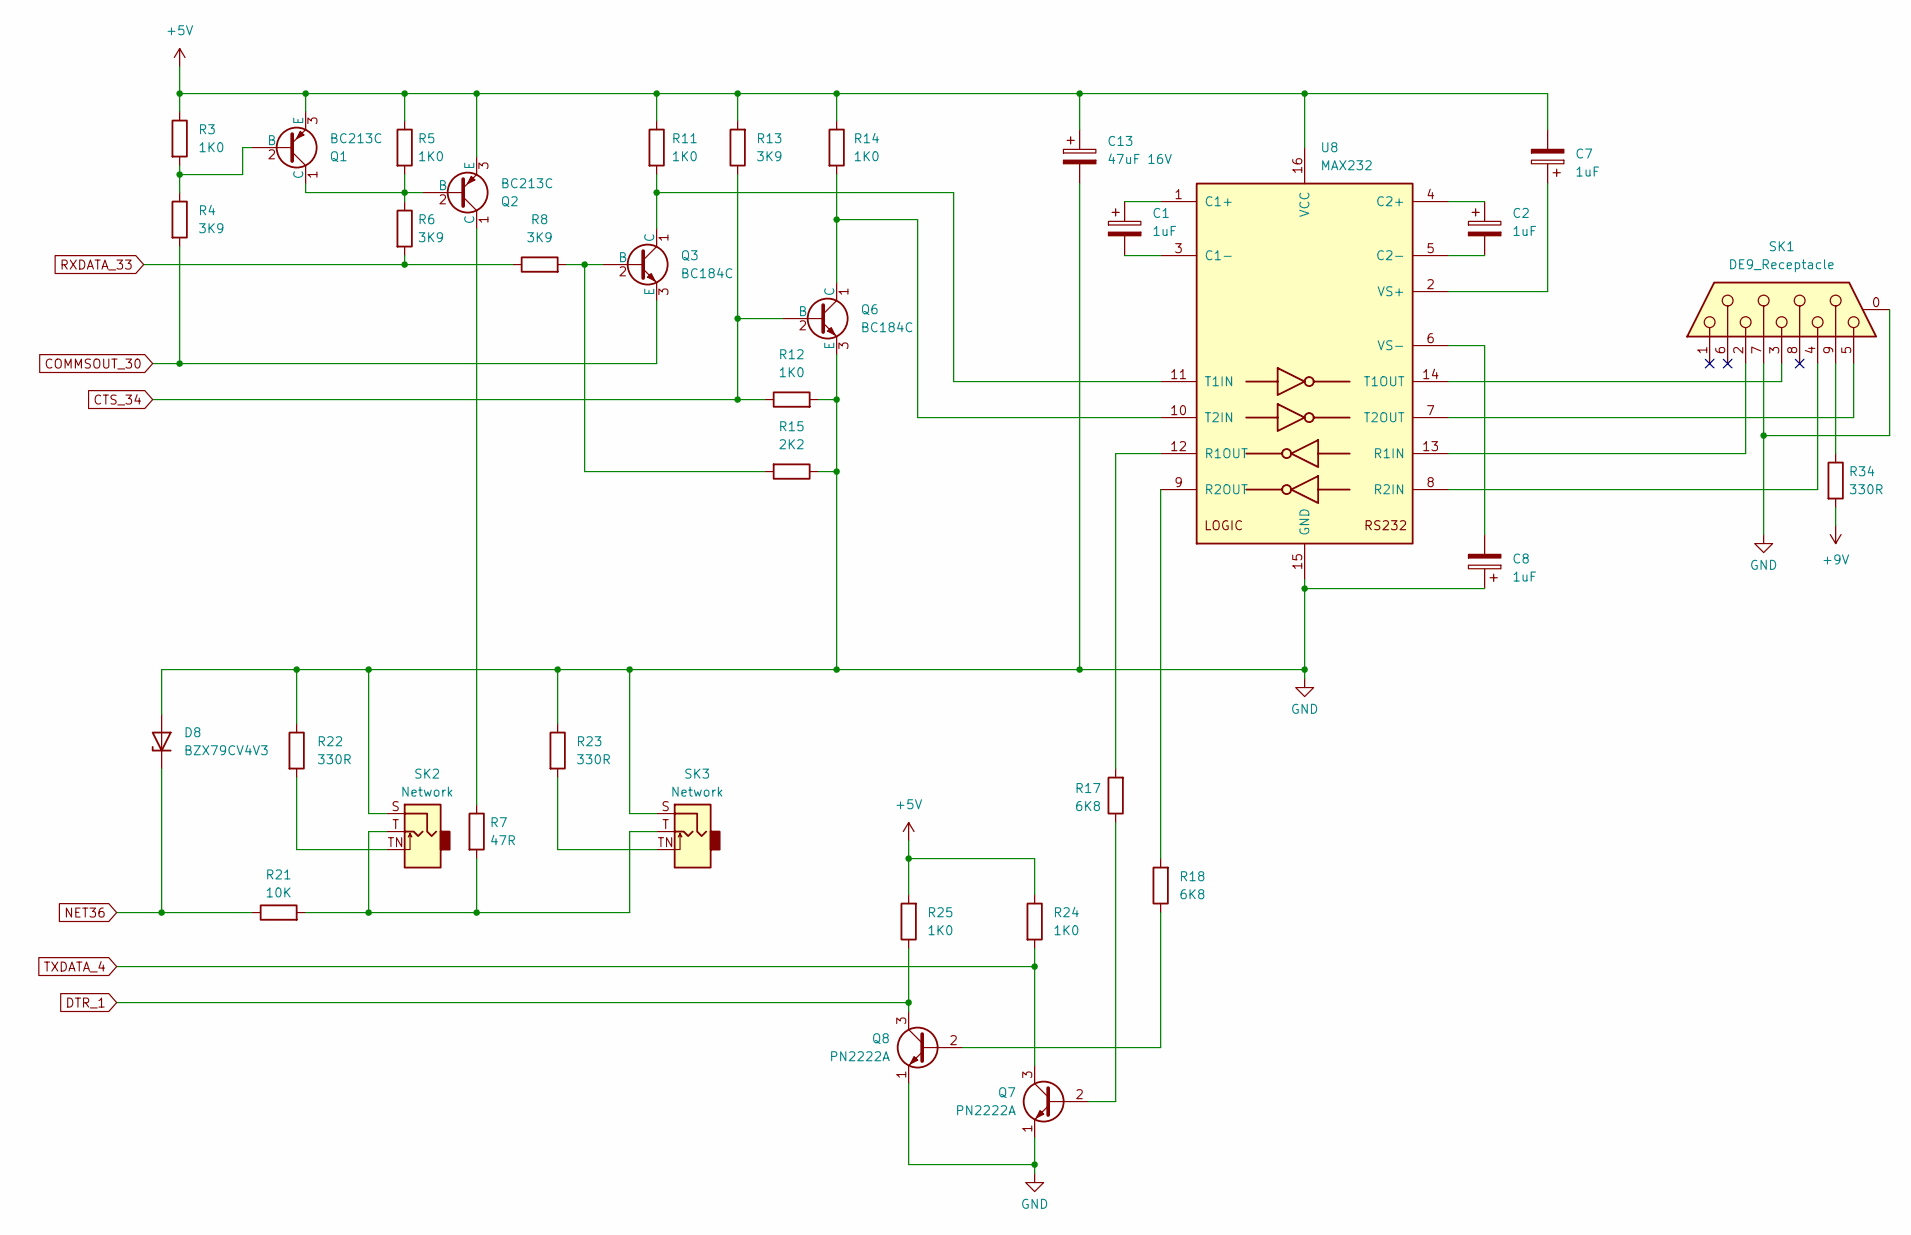
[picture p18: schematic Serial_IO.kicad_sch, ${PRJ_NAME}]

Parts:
C1, C2, C7, C8: 1uF; CP_Radial_D5.0mm_P2.50mm
C13: 47uF 16V; CP_Radial_D5.0mm_P2.50mm
D8: BZX79CV4V3; D_DO-35_SOD27_P10.16mm_Horizontal
Q1, Q2: BC213C; TO-92L_Inline_Wide
Q3, Q6: BC184C; TO-92L_Inline_Wide
Q7, Q8: PN2222A; TO-92_Inline_Wide
R3, R5, R11, R12, R14, R24, R25: 1K0; R_Axial_DIN0207_L6.3mm_D2.5mm_P10.16mm_Horizontal
R4, R6, R8, R13: 3K9; R_Axial_DIN0207_L6.3mm_D2.5mm_P10.16mm_Horizontal
R7: 47R; R_Axial_DIN0207_L6.3mm_D2.5mm_P10.16mm_Horizontal
R15: 2K2; R_Axial_DIN0207_L6.3mm_D2.5mm_P10.16mm_Horizontal
R17, R18: 6K8; R_Axial_DIN0207_L6.3mm_D2.5mm_P10.16mm_Horizontal
R21: 10K; R_Axial_DIN0207_L6.3mm_D2.5mm_P10.16mm_Horizontal
R22, R23, R34: 330R; R_Axial_DIN0207_L6.3mm_D2.5mm_P10.16mm_Horizontal
SK1: DE9_Receptacle; DSUB-9_Socket_Horizontal_P2.77x2.84mm_EdgePinOffset14.56mm_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
SK2, SK3: Network; ZX Spectrum 3.5mm Skt
U8: MAX232; DIP-16_W7.62mm

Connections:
+5V: C7.2, C13.1, Q1.3 (E), Q2.3 (E), R3.1, R5.1, R11.1, R13.2, R14.1, R24.1, R25.2, U8.16 (VCC); also elsewhere on the board
+9V: R34.2; also elsewhere on the board
COMMSOUT_30: Q3.3 (E), R4.2; also elsewhere on the board
CTS_34: Q6.2 (B), R12.1, R13.1; also elsewhere on the board
DTR_1: Q8.3 (C), R25.1; also elsewhere on the board
GND: C8.1, C13.2, D8.2 (A), Q6.3 (E), Q7.1 (E), Q8.1 (E), R12.2, R15.1, R22.1, R23.1, SK1.0 (PAD), SK1.7, SK2.S, SK3.S, U8.15 (GND); also elsewhere on the board
NET36: D8.1 (K), R21.1; also elsewhere on the board
unnamed: Q1.2 (B), R3.2, R4.1
unnamed: Q1.1 (C), Q2.2 (B), R5.2, R6.1
unnamed: Q2.1 (C), R7.1
unnamed: Q3.2 (B), R8.2, R15.2
unnamed: Q3.1 (C), R11.2, U8.11 (T1IN)
unnamed: Q6.1 (C), R14.2, U8.10 (T2IN)
unnamed: Q7.2 (B), R17.1
unnamed: Q8.2 (B), R18.1
unnamed: R7.2, R21.2, SK2.T, SK3.T
unnamed: R22.2, SK2.TN
unnamed: R23.2, SK3.TN
unnamed: R34.1, SK1.9
unnamed: C1.1, U8.1 (C1+)
unnamed: C1.2, U8.3 (C1-)
unnamed: C2.1, U8.4 (C2+)
unnamed: C2.2, U8.5 (C2-)
unnamed: SK1.2, U8.13 (R1IN)
unnamed: R17.2, U8.12 (R1OUT)
unnamed: SK1.4, U8.8 (R2IN)
unnamed: R18.2, U8.9 (R2OUT)
unnamed: SK1.3, U8.14 (T1OUT)
unnamed: SK1.5, U8.7 (T2OUT)
unnamed: C7.1, U8.2 (VS+)
unnamed: C8.2, U8.6 (VS-)
RXDATA_33: R6.2, R8.1; also elsewhere on the board
TXDATA_4: Q7.3 (C), R24.2; also elsewhere on the board

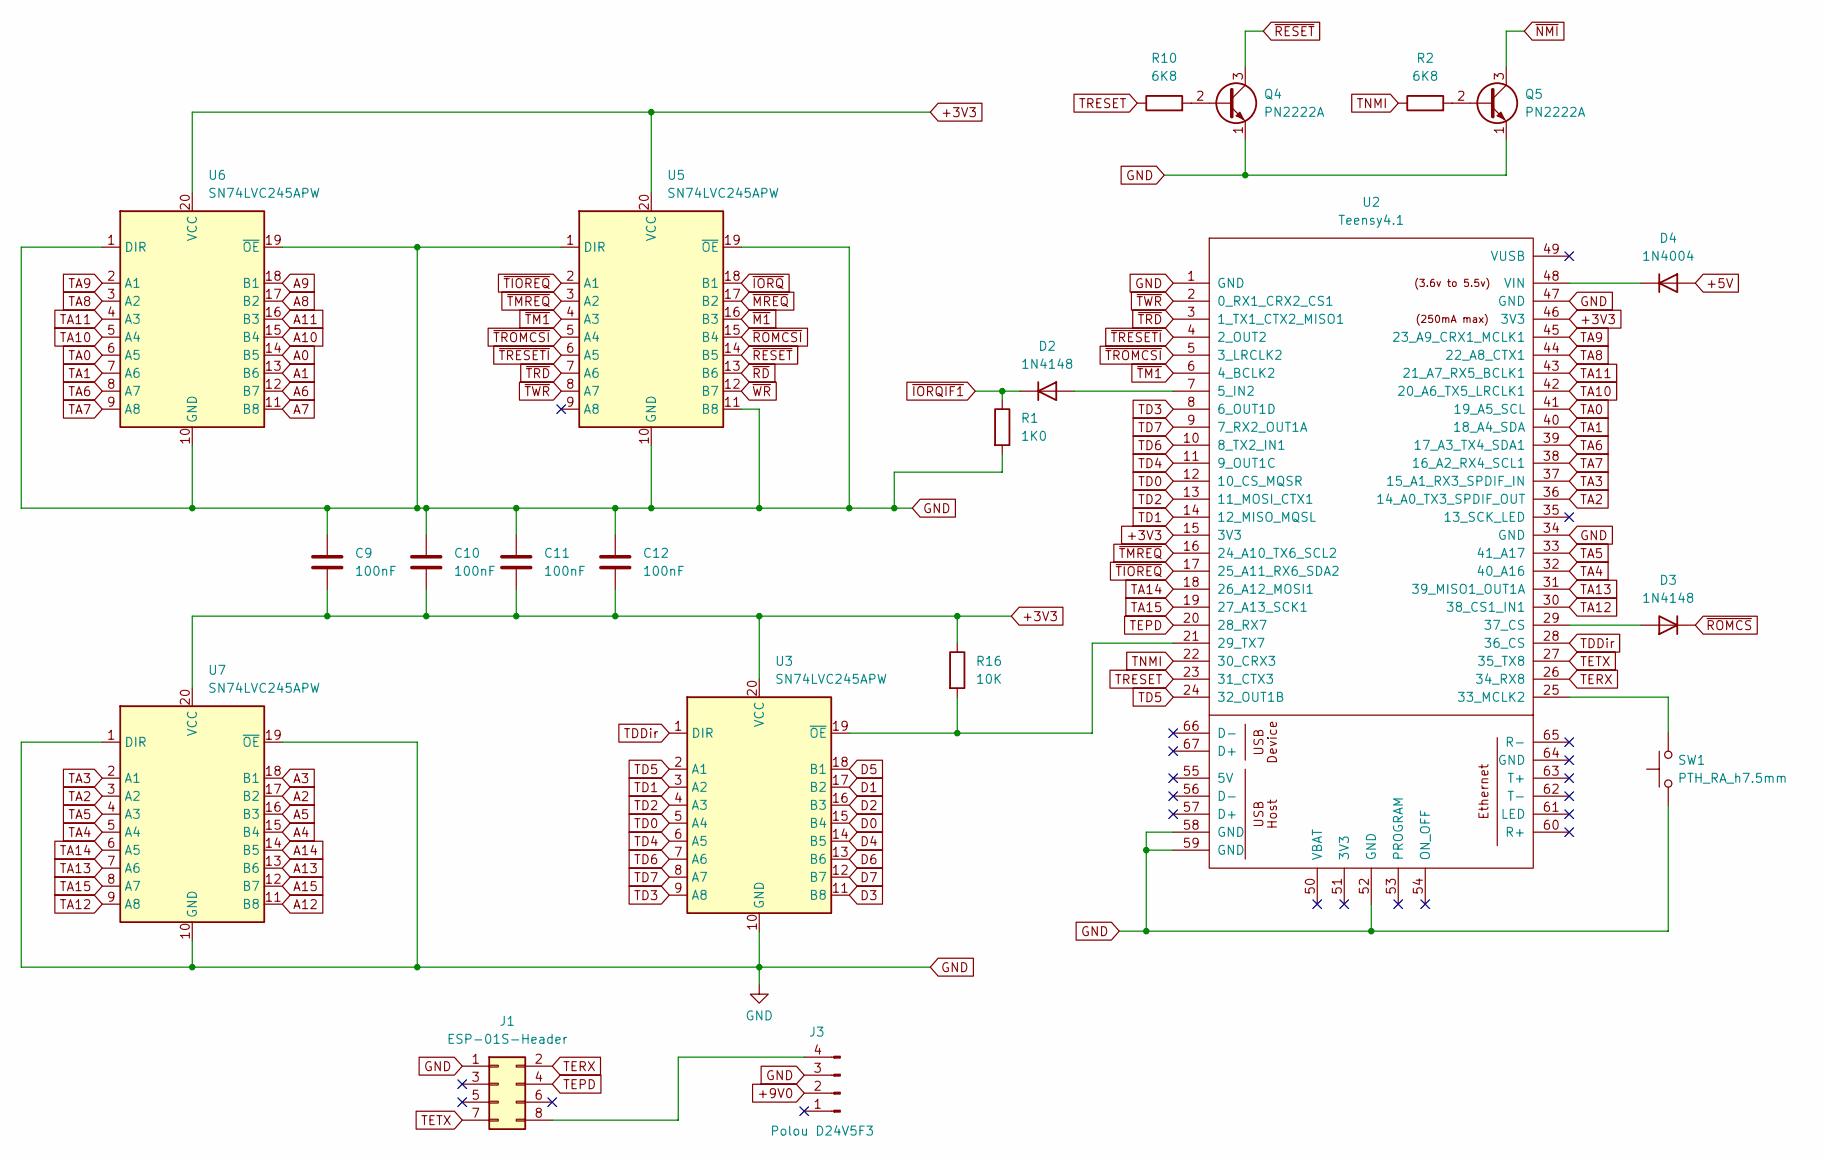
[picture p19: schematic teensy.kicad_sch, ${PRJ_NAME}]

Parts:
C9, C10, C11, C12: 100nF; C_Disc_D3.4mm_W2.1mm_P2.50mm
D2, D3: 1N4148; D_DO-35_SOD27_P7.62mm_Horizontal
D4: 1N4004; D_DO-41_SOD81_P10.16mm_Horizontal
J1: ESP-01S-Header; PinSocket_2x04_P2.54mm_Vertical
J3: Polou D24V5F3; PinSocket_1x04_P2.54mm_Vertical
Q4, Q5: PN2222A; TO-92_Inline_Wide
R1: 1K0; R_Axial_DIN0207_L6.3mm_D2.5mm_P7.62mm_Horizontal
R2, R10: 6K8; R_Axial_DIN0207_L6.3mm_D2.5mm_P7.62mm_Horizontal
R16: 10K; R_Axial_DIN0207_L6.3mm_D2.5mm_P10.16mm_Horizontal
SW1: PTH_RA_h7.5mm; Push_PTH_RA_8-020_h7.5mm; Mfg Part# 8-020 TS H = 7.5mm
U2: Teensy4.1; Teensy41
U3, U5, U6, U7: SN74LVC245APW; DIP-20_W7.62mm

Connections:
+3V3: C9.2, C10.2, C11.2, C12.2, R16.1, U2.15 (3V3), U2.46 (3V3), U3.20 (VCC), U5.20 (VCC), U6.20 (VCC), U7.20 (VCC)
+5V: D4.2 (A); also elsewhere on the board
+9V0: J3.2; also elsewhere on the board
A0: U6.14 (B5); also elsewhere on the board
A1: U6.13 (B6); also elsewhere on the board
A2: U7.17 (B2); also elsewhere on the board
A3: U7.18 (B1); also elsewhere on the board
A4: U7.15 (B4); also elsewhere on the board
A5: U7.16 (B3); also elsewhere on the board
A6: U6.12 (B7); also elsewhere on the board
A7: U6.11 (B8); also elsewhere on the board
A8: U6.17 (B2); also elsewhere on the board
A9: U6.18 (B1); also elsewhere on the board
A10: U6.15 (B4); also elsewhere on the board
A11: U6.16 (B3); also elsewhere on the board
A12: U7.11 (B8); also elsewhere on the board
A13: U7.13 (B6); also elsewhere on the board
A14: U7.14 (B5); also elsewhere on the board
A15: U7.12 (B7); also elsewhere on the board
D0: U3.15 (B4); also elsewhere on the board
D1: U3.17 (B2); also elsewhere on the board
D2: U3.16 (B3); also elsewhere on the board
D3: U3.11 (B8); also elsewhere on the board
D4: U3.14 (B5); also elsewhere on the board
D5: U3.18 (B1); also elsewhere on the board
D6: U3.13 (B6); also elsewhere on the board
D7: U3.12 (B7); also elsewhere on the board
GND: C9.1, C10.1, C11.1, C12.1, J1.1, J3.3, Q4.1 (E), Q5.1 (E), R1.2, SW1.1, U2.1 (GND), U2.34 (GND), U2.47 (GND), U2.52 (GND), U2.58 (GND), U2.59 (GND), U3.10 (GND), U5.1 (DIR), U5.10 (GND), U5.11 (B8), U5.19 (~OE), U6.1 (DIR), U6.10 (GND), U6.19 (~OE), U7.1 (DIR), U7.10 (GND), U7.19 (~OE); also elsewhere on the board
unnamed: D2.2 (A), U2.7 (5_IN2)
unnamed: D3.2 (A), U2.29 (37_CS)
unnamed: D4.1 (K), U2.48 (VIN)
unnamed: J1.8, J3.4
unnamed: Q4.2 (B), R10.2
unnamed: Q5.2 (B), R2.2
unnamed: R16.2, U2.21 (29_TX7), U3.19 (~OE)
unnamed: SW1.2, U2.25 (33_MCLK2)
TA0: U2.41 (19_A5_SCL), U6.6 (A5)
TA1: U2.40 (18_A4_SDA), U6.7 (A6)
TA2: U2.36 (14_A0_TX3_SPDIF_OUT), U7.3 (A2)
TA3: U2.37 (15_A1_RX3_SPDIF_IN), U7.2 (A1)
TA4: U2.32 (40_A16), U7.5 (A4)
TA5: U2.33 (41_A17), U7.4 (A3)
TA6: U2.39 (17_A3_TX4_SDA1), U6.8 (A7)
TA7: U2.38 (16_A2_RX4_SCL1), U6.9 (A8)
TA8: U2.44 (22_A8_CTX1), U6.3 (A2)
TA9: U2.45 (23_A9_CRX1_MCLK1), U6.2 (A1)
TA10: U2.42 (20_A6_TX5_LRCLK1), U6.5 (A4)
TA11: U2.43 (21_A7_RX5_BCLK1), U6.4 (A3)
TA12: U2.30 (38_CS1_IN1), U7.9 (A8)
TA13: U2.31 (39_MISO1_OUT1A), U7.7 (A6)
TA14: U2.18 (26_A12_MOSI1), U7.6 (A5)
TA15: U2.19 (27_A13_SCK1), U7.8 (A7)
TD0: U2.12 (10_CS_MQSR), U3.5 (A4)
TD1: U2.14 (12_MISO_MQSL), U3.3 (A2)
TD2: U2.13 (11_MOSI_CTX1), U3.4 (A3)
TD3: U2.8 (6_OUT1D), U3.9 (A8)
TD4: U2.11 (9_OUT1C), U3.6 (A5)
TD5: U2.24 (32_OUT1B), U3.2 (A1)
TD6: U2.10 (8_TX2_IN1), U3.7 (A6)
TD7: U2.9 (7_RX2_OUT1A), U3.8 (A7)
TDDir: U2.28 (36_CS), U3.1 (DIR)
TEPD: J1.4, U2.20 (28_RX7)
TERX: J1.2, U2.26 (34_RX8)
TETX: J1.7, U2.27 (35_TX8)
TNMI: R2.1, U2.22 (30_CRX3)
TRESET: R10.1, U2.23 (31_CTX3)
~IORQIF1: D2.1 (K), R1.1; also elsewhere on the board
~IORQ: U5.18 (B1); also elsewhere on the board
~M1: U5.16 (B3); also elsewhere on the board
~MREQ: U5.17 (B2); also elsewhere on the board
~NMI: Q5.3 (C); also elsewhere on the board
~RD: U5.13 (B6); also elsewhere on the board
~RESET: Q4.3 (C), U5.14 (B5); also elsewhere on the board
~ROMCSI: U5.15 (B4); also elsewhere on the board
~ROMCS: D3.1 (K); also elsewhere on the board
~TIOREQ: U2.17 (25_A11_RX6_SDA2), U5.2 (A1)
~TM1: U2.6 (4_BCLK2), U5.4 (A3)
~TMREQ: U2.16 (24_A10_TX6_SCL2), U5.3 (A2)
~TRD: U2.3 (1_TX1_CTX2_MISO1), U5.7 (A6)
~TRESETI: U2.4 (2_OUT2), U5.6 (A5)
~TROMCSI: U2.5 (3_LRCLK2), U5.5 (A4)
~TWR: U2.2 (0_RX1_CRX2_CS1), U5.8 (A7)
~WR: U5.12 (B7); also elsewhere on the board

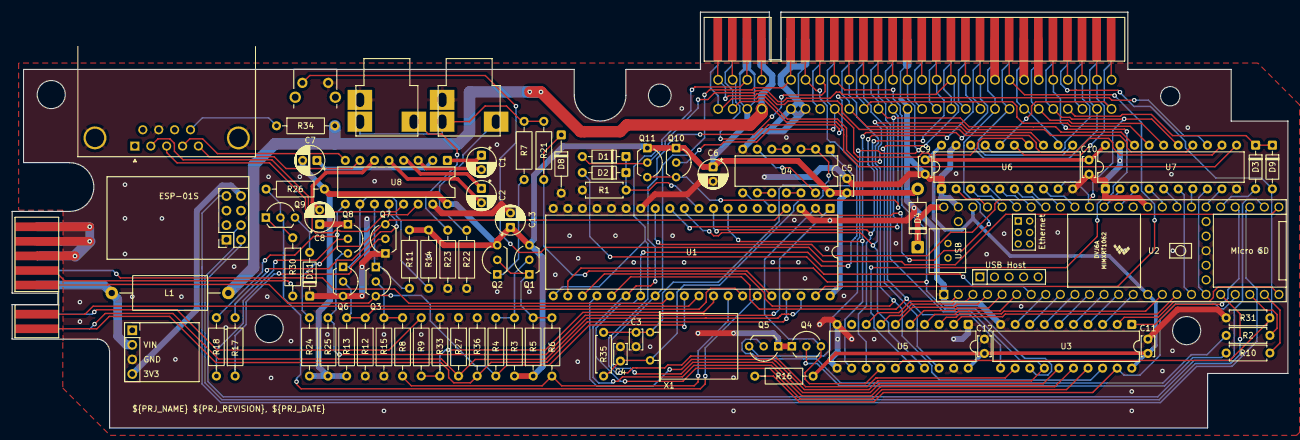
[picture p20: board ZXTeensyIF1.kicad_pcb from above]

Board: 2 copper layers, 222.4 x 72.5 mm, 81 parts (0 on the bottom side), 148 nets.

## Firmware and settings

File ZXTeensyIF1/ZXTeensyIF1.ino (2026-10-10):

#include <SD.h>
#include <SdFat.h>
#include "USBHost_t36.h"
#include "WriteDataTable.h"
#include "RingBuffer.h"
#include "PrintableString.h"
#include "SdHdfZXTeensy.h"
#include "SdSdioZXTeensy.h"
#include "UartZXTeensy.h"
#include "RtcZXTeensy.h"
#include "EspNtpZXTeensy.h"
#include "TzxPlayerZXTeensy.h"
#include "Dsk765ZXTeensy.h"
#include "PrinterZXTeensy.h"
#include "DefinesZXTeensy.h"

extern "C" volatile uint32_t systick_millis_count;
extern "C" uint32_t set_arm_clock(uint32_t frequency);

static const char PROGMEM VERSION_STR[9] = ZXTEENSY_VERSION;

typedef enum {
    MENU_ACTION_TOP_MENU,
    MENU_ACTION_SETTING,
    MENU_ACTION_LOAD_CFG,
    MENU_ACTION_LOAD_ROM,
    MENU_ACTION_LOAD_CART,
    MENU_ACTION_UPDATE_FW,
    MENU_ACTION_NTP_TZ,
    MENU_ACTION_LOAD_NETMAN,
    MENU_ACTION_LOAD_RTC_SETUP,
    MENU_ACTION_BROWSER_CD,
    MENU_ACTION_BROWSER_PAGE,
    MENU_ACTION_BROWSER_EXPAND,
    MENU_ACTION_BROWSER_OPEN,
    MENU_ACTION_BROWSER_OPEN_ROM,
    MENU_ACTION_BROWSER_OPEN_HDF,
    MENU_ACTION_BROWSER_OPEN_DSK,
    MENU_ACTION_BROWSER_LOAD_CART,
    MENU_ACTION_BROWSER_LOAD_ZXC2,
    MENU_ACTION_BROWSER_LOAD_ZXC3,
    MENU_ACTION_BROWSER_LOAD_MLD,
    MENU_ACTION_BROWSER_LOAD_Z80,
    MENU_ACTION_BROWSER_LOAD_TZX,
    MENU_ACTION_BROWSER_LOAD_MDR,
    MENU_ACTION_BROWSER_LOAD_MF128,
    MENU_ACTION_BROWSER_OPEN_POK,
    MENU_ACTION_BROWSER_MOUNT_SDA,
    MENU_ACTION_BROWSER_MOUNT_SDB,
    MENU_ACTION_BROWSER_MOUNT_FDA,
    MENU_ACTION_BROWSER_MOUNT_FDB,
    MENU_ACTION_START_SERVER,
    MENU_ACTION_STOP_SERVER,
    MENU_ACTION_SELECT_LOAD_SLOT,
    MENU_ACTION_SELECT_SAVE_SLOT,
    MENU_ACTION_LOAD_STATE_SLOT,
    MENU_ACTION_POK_TOGGLE_TRAINER,
    MENU_ACTION_IN_GAME_EXIT,
    MENU_ACTION_IN_GAME_EXIT_TAPE,
    MENU_ACTION_IN_GAME_EXIT_BASIC,
    MENU_ACTION_IN_GAME_EXIT_48K,
    MENU_ACTION_IN_GAME_SEEK_TAPE,
    MENU_ACTION_IN_GAME_SAVE_STATE,
    MENU_ACTION_IN_GAME_APPLY_POK,
    MENU_ACTION_IN_GAME_UNMOUNT_FDA,
    MENU_ACTION_IN_GAME_UNMOUNT_FDB,
    MENU_ACTION_IN_GAME_EJECT_TAPE,
    MENU_ACTION_IN_GAME_NMI,
    MENU_ACTION_IN_GAME_MF128,
    MENU_ACTION_IN_GAME_DIVMMC,
    MENU_ACTION_IN_GAME_RESET
} menu_action_t;

typedef enum {
    ICON_TYPE_NONE,
    ICON_TYPE_DSK,
    ICON_TYPE_ZXC2,
    ICON_TYPE_CART,
    ICON_TYPE_Z80,
    ICON_TYPE_TZX
} icon_type_t;

typedef enum {
    POKE_PARSE_METADATA,
    POKE_PARSE_PREPARE,
    POKE_PARSE_APPLY
} poke_parse_op_t;

typedef enum {
    STATE_ROM_DISABLE = 0x00,
    STATE_ROM_ENABLE  = 0x01,
    STATE_RESET       = 0x02,
    STATE_RESET_MENU  = 0x03,
    STATE_RESET_HARD  = 0x07
} run_state_t;

typedef enum {
    TRIGGER_ACTIVE,
    TRIGGER_HOLD,
    TRIGGER_DELAY,
    TRIGGER_READY
} trigger_state_t;

typedef enum {
    BANK_ROM0   = 0x0001,
    BANK_ROM1   = 0x0002,
    BANK_ROM2   = 0x0004,
    BANK_ROM3   = 0x0008,
    BANK_IF1    = 0x0010,
    BANK_MF128  = 0x0020,
    BANK_DIVMMC = 0x0040,
    BANK_LPRINT = 0x0080,
    BANK_MENU   = 0x0100,
    BANK_RAM    = 0x0200
} bank_select_t;

// NOTE: This also defines the priority for active paged ROMs
typedef enum {
    // 16KB ROMs
    ROM_ROM0,
    ROM_ROM1,
    ROM_ROM2,
    ROM_ROM3,
    ROM_IF1,
    // 8KB ROM and 8KB RAM
    ROM_MF128,
    // 8KB ROMs
    ROM_DIVMMC,
    // ROM_LPRINT uses separate 2KB ROM array
    ROM_LPRINT,
    // "Dynamic ROMs" that use DivMMC RAM
    ROM_MODEM,
    ROM_ZXC2,
    ROM_MLD,
    ROM_SNA,
    // Menu ROM as highest priority
    ROM_MENU
} rom_select_t;

typedef enum {
    ROM_PAGE_ROM0      = 0,
    ROM_PAGE_ROM1      = 2,
    ROM_PAGE_ROM2      = 4,
    ROM_PAGE_ROM3      = 6,
    ROM_PAGE_IF1       = 8,
    ROM_PAGE_MF128     = 10,
    ROM_PAGE_DIVMMC    = 12,
    ROM_PAGE_MENU      = 13,
    ROM_PAGE_COUNT
} rom_page_t;

typedef enum {
    TYPE_ROM,
    TYPE_ZXC2,
    TYPE_ZXC3,
    TYPE_CART,
    TYPE_Z80,
    TYPE_SNA,
    TYPE_MLD
} rom_type_t;

typedef enum {
    SD_SPI_WRITE,
    SD_SPI_SELECT
} sd_spi_action_t;

typedef enum {
    DIVMMC_NONE,
    DIVMMC_SDHC,
    DIVMMC_HDF_A,
    DIVMMC_HDF_B
} divmmc_spi_t;

typedef enum {
    ZXC3_FLASH_IDLE,
    ZXC3_FLASH_UNLOCK,
    ZXC3_FLASH_CMD,
    ZXC3_FLASH_WRITE
} zxc3_flash_state_t;

typedef enum {
    MLD_PULSE_IDLE,
    MLD_PULSE_COMMAND,
    MLD_PULSE_DATA1,
    MLD_PULSE_DATA2,
    MLD_PULSE_FAST
} mld_pulse_state_t;

typedef enum {
    MLD_EEP_IDLE,
    MLD_EEP_PROGRAM_BYTE,
    MLD_EEP_ERASE_SECTOR,
    MLD_EEP_PROGRAM_SECTOR
} mld_eep_program_t;

typedef enum {
    MENU_ROM_CMD_IDLE = 0,
    MENU_ROM_CMD_REDRAW = 1,
    MENU_ROM_CMD_IN_GAME_EXIT = 2,
    MENU_ROM_CMD_STATE_CAPTURE_48 = 3,
    MENU_ROM_CMD_STATE_CAPTURE_128 = 4,
    MENU_ROM_CMD_STATE_BLOCK_DONE = 5,
    MENU_ROM_CMD_STATE_COMPLETE = 6,
    MENU_ROM_CMD_STATE_FAILED = 7,
    MENU_ROM_CMD_STATE_PREVIEW = 8,
    MENU_ROM_CMD_BROWSER_EXPAND = 9
} menu_rom_action_t;

// I/O pin assignments
static const uint8_t LED_PIN = 13;
static const uint8_t DATA_DIS_PIN = 29;
static const uint8_t DATA_OUT_PIN = 36;  // 1 = output, 0 = input
static const uint8_t RESET_PIN = 31;
static const uint8_t RESET_IN_PIN = 2;
static const uint8_t BUTTON_PIN = 33;
static const uint8_t ROMCS_PIN = 37;
static const uint8_t ROMCS_IN_PIN = 3;
static const uint8_t IF1_DIS_PIN = 5;
static const uint8_t NMI_PIN = 30;
static const uint8_t RD_PIN = 1;
static const uint8_t WR_PIN = 0;
static const uint8_t MREQ_PIN = 24;
static const uint8_t IOREQ_PIN = 25;
static const uint8_t M1_PIN = 4;
static const uint8_t ESP_ENABLE = 28;
static const uint8_t SD_CS_PIN = 46;

static const uint8_t INPUT_PINS[] = {
    RESET_IN_PIN, MREQ_PIN, RD_PIN, IOREQ_PIN, WR_PIN, M1_PIN, ROMCS_IN_PIN,
    19, 18, 14, 15, 40, 41, 17, 16, 22, 23, 20, 21, 38, 39, 26, 27, // Address bus
    BUTTON_PIN, ESP_ENABLE
};

static const uint32_t RD_PIN_BITMASK = CORE_PIN1_BITMASK;
static const uint32_t WR_PIN_BITMASK = CORE_PIN0_BITMASK;
static const uint32_t M1_PIN_BITMASK = CORE_PIN4_BITMASK;
static const uint32_t IOREQ_PIN_BITMASK = CORE_PIN25_BITMASK;
static const uint32_t MREQ_PIN_BITMASK = CORE_PIN24_BITMASK;
static const uint32_t A15_PIN_BITMASK = CORE_PIN27_BITMASK;
static const uint32_t A14_PIN_BITMASK = CORE_PIN26_BITMASK;
static const uint32_t A13_PIN_BITMASK = CORE_PIN39_BITMASK;
static const uint32_t A12_PIN_BITMASK = CORE_PIN38_BITMASK;
static const uint32_t ROMCS_IN_PIN_BITMASK = CORE_PIN3_BITMASK;
static const uint32_t DATA_OUT_PIN_BITMASK = CORE_PIN36_BITMASK;

static const uint8_t DATA_PINS[] = { 6, 7, 8, 9, 10, 11, 12, 32 };

static const uint32_t GPIO7_DATA_MASK = (CORE_PIN6_BITMASK | CORE_PIN7_BITMASK |
    CORE_PIN8_BITMASK | CORE_PIN9_BITMASK |
    CORE_PIN10_BITMASK | CORE_PIN11_BITMASK |
    CORE_PIN12_BITMASK | CORE_PIN32_BITMASK);

static const uint8_t OUTPUT_PINS[] = {
    LED_PIN, ROMCS_PIN, NMI_PIN, IF1_DIS_PIN
};

// Mask for A15 and A14 and ^MREQ
static const uint32_t ROM_ADDRESS_MASK = (A15_PIN_BITMASK | A14_PIN_BITMASK | MREQ_PIN_BITMASK);

// Number of SD detection retries
static const uint8_t NUM_SD_RETRIES = 5;

// Global state
volatile bool bootIntoMenu = false;
volatile bool afterFirstReset = false;
volatile bool isDeviceDisabled = false;
volatile bool loadRomSets = false;
volatile bool sdCardPresent = false;
volatile bool sdioEnabled = false;
volatile run_state_t globalState = STATE_RESET;
volatile bool busRdActive = false;
volatile bool nmiPending = false;
volatile rom_select_t nmiRomTarget = ROM_ROM0;

// State save and load
volatile int8_t stateActiveSlot = -1;
volatile uint8_t stateSaveSlot = 0;
volatile bool stateStartLoad = false;

// Reset and NMI debouncing
volatile trigger_state_t resetTrigState = TRIGGER_ACTIVE;
volatile uint32_t resetTrigExitCount = TRIGGER_DELAY_CNT;
volatile uint32_t resetHardTrigCount = HARD_RESET_DELAY_CNT;
volatile bool resetHardTrigArmed = false;
volatile trigger_state_t buttonTrigState = TRIGGER_READY;
volatile uint32_t buttonTrigExitCount = 0;

// Soft ROM storage
// NOTE: Workaround for LTO optimisation placing PROGMEM/FLASHMEM into RAM1.
// The built-in ROMs had been constant arrays marked for Flash memory, but the
// LTO optimisation places them back into RAM1 - so, given RAM1 is already
// initialised, move to doing a direct initialisation with the built-in ROMs
static const uint16_t RAM_PAGE_SIZE = 0x2000;
static const uint16_t ROM_PAGE_SIZE = (RAM_PAGE_SIZE * 2);
static const uint16_t LPRINT_ROM_SIZE = 0x800;
volatile uint8_t lprintRom[LPRINT_ROM_SIZE] __attribute__((aligned(16)));
volatile uint8_t romArray[ROM_PAGE_COUNT][RAM_PAGE_SIZE] __attribute__((aligned(16))) = {
    {}, // ROM_PAGE_ROM0
    {},
    {}, // ROM_PAGE_ROM1
    {},
    {}, // ROM_PAGE_ROM2
    {},
    {}, // ROM_PAGE_ROM3
    {},
    // ROM_PAGE_IF1
#ifdef ENABLE_BUILTIN_ROM_IF1
#include "if1-2_rom.h"
#else
    {},
#endif
    {},
    // ROM_PAGE_MF128
#ifdef ENABLE_BUILTIN_ROM_MF128
#include "mf128_rom.h"
#else
    {},
#endif
    {}, // (Multiface 128 RAM)
    {}, // ROM_PAGE_DIVMMC
    {}  // ROM_PAGE_MENU
};

// Soft ROM banking
volatile rom_select_t romSelected = ROM_ROM0;
volatile bank_select_t romArraySelected = BANK_ROM0;
volatile uint32_t romPaged = 0x01;
volatile uint8_t* romPtr = romArray[0];
volatile uint16_t romArrayPresent = 0;
volatile bool romEnabled = false;
volatile bool romCsPending = false;
volatile bool romCsEnable = false;

// Spectrum 128k/+3 ROMs
volatile bool rom1Present = false;
volatile bool rom23Present = false;
volatile bool rom1Paged = false;
volatile bool rom23Paged = false;

// DivMMC with total 512KB of RAM
static const uint16_t RAM_PAGE_COUNT = 16;
static const uint16_t EXT_RAM_PAGE_COUNT = 48;
volatile uint8_t divMmcRamArray[RAM_PAGE_COUNT][RAM_PAGE_SIZE] __attribute__((aligned(16)));
volatile DMAMEM uint8_t divMmcExtRamArray[EXT_RAM_PAGE_COUNT][RAM_PAGE_SIZE] __attribute__((aligned(16)));
typedef struct {
    bool present;
    bool romPresent;
    bool enabled;
    bool extRamPresent;
    bool romEnabled;
    bool sdReadOnly;
    bool toggle;
    bool autoMap;
    bool conMem;
    bool mapRam;
    bool allRamPresent;
    bool allRamEnabled;
    bool allRam;
    bool allRamActive;
    bool writeLock;
    bool mapDisable;
    bool mapRamPage;
    bool bankRom23;
    bool bankRom01;
    bool bankRom01Locked;
    uint8_t ramBank;
    bool ramBankMapRam;
    bool preserveRam;
    bool extRamEnabled;
} div_mmc_state_t;
volatile div_mmc_state_t divMmcState = {};
volatile uint8_t* divMmcRomPtr = romArray[ROM_PAGE_DIVMMC];
volatile uint8_t* divMmcRamPtr = divMmcRamArray[0];

// Multiface 128
volatile bool mf128Present = false;
volatile bool mf128Enabled = false;
volatile bool mf128ActiveNMI = false;
volatile bool mf128LoadGenie = false;

// Interface 1
volatile bool interface1Present = false;
volatile bool interface1Enabled = false;
volatile bool interface1Removed = false;

// ZXC2 cartridge
volatile bool zxC2Present = false;
volatile bool zxC2Lock = false;
volatile bool zxC2ShadowRom = false;
volatile uint8_t zxC2RomBank = 0x00;

// Dandanator Mini flash cartridge
static const uint16_t MLD_HEADER_OFFSET = 0x3FEA;
static const uint16_t MLD_SIGNATURE_OFFSET = 0x3FFC;
static const uint8_t MLD_MAX_PAGE_COUNT = RAM_PAGE_COUNT + EXT_RAM_PAGE_COUNT;
static const uint8_t MLD_MAX_SLOT_COUNT = MLD_MAX_PAGE_COUNT / 2;
static const uint8_t MLD_SECTORS_PER_SLOT = 4;
static const uint8_t MLD_MAX_SAVE_SECTOR_COUNT = 4;
static const uint8_t MLD_SECTOR_COUNT = MLD_MAX_PAGE_COUNT * 2;
static const uint32_t MLD_PULSE_TIMEOUT_CNT =
    (uint32_t)((TEENSY_CLK_FREQ / 1000000ULL) * 32ULL);
static const uint32_t MLD_SPECIAL_TIMEOUT_CNT =
    (uint32_t)((TEENSY_CLK_FREQ / 1000000ULL) * 512ULL);
volatile bool mldPresent = false;
volatile uint8_t mldSlotCount = 0;
volatile bool mldCmdLocked = false;
volatile bool mldCmdDisabled = false;
volatile uint8_t mldCurrentSlot = 1;
volatile uint8_t mldPreviousSlot = 1;
volatile mld_eep_program_t mldEepProgram = MLD_EEP_IDLE;
volatile uint8_t mldEepSector = 0x00;
volatile uint16_t mldEepProgramRemaining = 0;
volatile uint8_t mldCmdOpcode = 0x00;
volatile uint8_t mldCmdData1 = 0x00;
volatile uint8_t mldCmdData2 = 0x00;
volatile uint16_t mldCmdRepeat = 0x0000;
volatile mld_pulse_state_t mldPulseState = MLD_PULSE_IDLE;
volatile uint32_t mldPulseCycle = 0;

// ZXC3 flash cartridge
static const uint16_t ZXC3_PAGE_COUNT = 16;
static const size_t ZXC3_ERASE_BUSY_SECTORS_SIZE = (MLD_SECTOR_COUNT + 7) / 8;
volatile bool zxC3Present = false;
volatile bool zxC3Write = false;
volatile bool zxC3EraseBusy = false;
volatile uint8_t zxC3EraseBusySectors[ZXC3_ERASE_BUSY_SECTORS_SIZE];
volatile zxc3_flash_state_t zxC3FlashState = ZXC3_FLASH_IDLE;
volatile bool zxC3FlashSetup = false;
volatile trigger_state_t zxC3WriteTrigState = TRIGGER_READY;
volatile uint32_t zxC3WriteTrigExitCount = 0;
volatile trigger_state_t zxC3EraseTrigState = TRIGGER_READY;
volatile uint32_t zxC3EraseTrigExitCount = 0;
RingBuffer<MLD_SECTOR_COUNT> zxC3EraseBuffer;

// Microdrive emulator
static const uint8_t MDR_MAX_SECTOR = 0xB4;
volatile bool mdrPresent = false;
volatile bool mdrEnabled = false;
volatile uint8_t mdrMaxSector = 0;
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
FASTRUN void loop()
{
    // Detect reset entry, and perform actions in reset
    if (isGlobalStateReset())
    {
        handleStateReset();
    }

    // Run actions (eg. SD SPI) on regular ticks
    uint32_t cycle_ = ARM_DWT_CYCCNT;
    if ((cycle_ - globalCycleCount) >= TICK_CYCCNT)
    {
        globalCycleCount = cycle_;

        // Perform tick updates at TICK_FREQ
        sdSpiOnTick();
        espUart.onTick();
        tzxPlayer.onTick();
        zxC3OnTick();
        printerPort.onTick();
        if (wifiNtpEnabled && wifiNtp.onTick())
        {
            // Update the RTC now time has been received
            wifiNtpEnabled = false;
            rtcTeensy.setAscTime(wifiNtp.getAscTime(), wifiNtpTz);
            rtcHasTime = true;
            menuRedraw = true;
            wifiNtp.end();

            // Enable the UART when not in menu, now time is updated
            if (uartPresent && (IS_ROM_PAGED(ROM_MENU) == 0))
            {
                espUart.end(false);
                if (modemPresent)
                {
                    espUart.begin(0, menuGetModemUrl());
                    modemOnReset = true;
                    modemEnabled = true;
                } else {
                    espUart.begin(0, 0);
                    uartEnabled = true;
                }
            }
        }

        // Trigger NMI to enter the menu, when requested
        if (menuTriggerNMI && (divMmcDrive == DIVMMC_NONE))
        {
            // Prepare the in-game menu
            menuBeginInGame();

            // Trigger NMI to page in the menu ROM
            nmiRomTarget = ROM_MENU;
            nmiPending = true;
            menuTriggerNMI = false;
            digitalWriteFast(NMI_PIN, 1);
        }

        // Trigger exit from menu with NMI, when requested
        if (menuTriggerExitNMI && IS_ROM_PAGED(ROM_MENU))
        {
            menuSelected = false;
            menuTriggerExitNMI = false;
            nmiRomTarget = (divMmcState.romEnabled ? ROM_DIVMMC : ROM_MF128);
            menuBuffer.write(MENU_ROM_CMD_IN_GAME_EXIT);
        }

        // Perform menu actions
        if (menuSelected)
        {
            menuSelected = false;
            if (menuPerformSelection(menuSelectedIndex))
            {
                bool exitMenu = true;
                switch (menuGetMenuAction())
                {
                    case MENU_ACTION_IN_GAME_EXIT_BASIC :
                        menuInGameExitBasic();
                        nmiRomTarget = ROM_ROM0;
                        break;
                    case MENU_ACTION_IN_GAME_EXIT_48K :
                        menuInGameExitDisable128k();
                        nmiRomTarget = ROM_ROM0;
                        break;
                    case MENU_ACTION_IN_GAME_EXIT_TAPE :
                        if (tzxEnabled)
                        {
                            if (tzxPlayer.isTapePaused())
                            {
                                tzxPlayer.unpause();
                            } else {
                                tzxPlayer.play();
                            }
                        }
                        nmiRomTarget = ROM_ROM0;
                        break;
                    case MENU_ACTION_IN_GAME_SAVE_STATE :
                        exitMenu = false;
                        if (!stateBeginSave(stateSaveSlot))
                        {
                            menuRedraw = true;
                            menuBuffer.write(MENU_ROM_CMD_STATE_FAILED);
                        }
                        break;
                    case MENU_ACTION_IN_GAME_APPLY_POK :
                        exitMenu = false;
                        stateActiveSlot = -1;
                        if (!stateBeginSave(STATE_POKE_SLOT))
                        {
                            pokeFinishApply();
                            menuRedraw = true;
                            menuBuffer.write(MENU_ROM_CMD_STATE_FAILED);
                        }
                        break;
                    case MENU_ACTION_IN_GAME_EXIT :
                        nmiRomTarget = ROM_ROM0;
                        break;
                    case MENU_ACTION_IN_GAME_NMI :
                        nmiRomTarget = ROM_ROM3;
                        break;
                    case MENU_ACTION_IN_GAME_MF128 :
                        nmiRomTarget = ROM_MF128;
                        break;
                    case MENU_ACTION_IN_GAME_DIVMMC :
                        nmiRomTarget = ROM_DIVMMC;
                        break;
                    case MENU_ACTION_IN_GAME_RESET :
                        // Hard reset into the main menu
                        menuCancelStateLoad();
                        setState(STATE_RESET_HARD);
                        break;
                    case MENU_ACTION_LOAD_STATE_SLOT :
                        // Reset to load the active state slot
                        setState(STATE_RESET_MENU);
                        break;
                    default :
                        // The menu needs the Spectrum in reset to access the SD card,
                        // reload ROMs, update FW etc.
                        stateActiveSlot = -1;
                        setState(STATE_RESET_MENU);
                        break;
                }

                // Update ROM indexes, and exit the menu
                if (exitMenu && !isGlobalStateReset())
                {
                    updateRomIndex(true);
                    menuBuffer.write(MENU_ROM_CMD_IN_GAME_EXIT);
                }
            } else {
                // Refresh the menu, by default
                menuRedraw = true;

                // Perform in-game actions
                switch (menuGetMenuAction())
                {
                    case MENU_ACTION_SELECT_LOAD_SLOT :
                        // The menu ROM is waiting for the preview command
                        menuGenerate();
                        menuBuffer.write(MENU_ROM_CMD_STATE_PREVIEW);
                        menuRedraw = false;
                        break;
                    case MENU_ACTION_BROWSER_EXPAND :
                        // The menu ROM is waiting for the expanded-name command
                        menuGenerate();
                        menuBuffer.write(MENU_ROM_CMD_BROWSER_EXPAND);
                        menuRedraw = false;
                        break;
                    case MENU_ACTION_BROWSER_LOAD_TZX :
                        if (isTzxRamAvailable() && beginSdfsSd())
                        {
                            tzxEnabled = tzxPlayer.begin(menuGetTapeFileName(),
                                divMmcExtRamArray[0], 0, menuMachineIs48k());
                            if (tzxEnabled && !tzxPlayer.isStreamingFile())
                            {
                                menuClearTapeFileName();
                            }
                        }
                        break;
                    case MENU_ACTION_IN_GAME_EJECT_TAPE :
                        tzxPlayer.end();
                        menuClearTapeFileName();
                        tzxEnabled = false;
                        break;
                    case MENU_ACTION_BROWSER_LOAD_MF128 :
                        if (mf128Present && beginSdfsSd())
                        {
                            memset((void*)&(romArray[ROM_PAGE_MF128][RAM_PAGE_SIZE]),
                                0xFF, RAM_PAGE_SIZE);
                            loadRomImage(menuGetBrowserPath(),
                                (char*)&(romArray[ROM_PAGE_MF128][RAM_PAGE_SIZE]),
                                RAM_PAGE_SIZE);
                        }
                        break;
                    case MENU_ACTION_BROWSER_MOUNT_FDA :
                    case MENU_ACTION_BROWSER_MOUNT_FDB :
                    case MENU_ACTION_IN_GAME_UNMOUNT_FDA :
                    case MENU_ACTION_IN_GAME_UNMOUNT_FDB :
                        if (dskEnabled && !dskController.isMotorOn() && beginSdfsSd())
                        {
                            dskController.insertDisks(menuGetFdcFdaPath(),
                                menuGetFdcFdbPath());
                        }
                        break;
                    default :
                        break;
                }
            }
        }

        // Re-generate and re-draw the menu, when requested
        if (menuRedraw)
        {
            menuRedraw = false;
            if (IS_ROM_PAGED(ROM_MENU) && !nmiPending)
            {
                menuGenerate();
                menuBuffer.write(MENU_ROM_CMD_REDRAW);
            }
        }
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

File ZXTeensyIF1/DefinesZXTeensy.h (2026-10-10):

#ifndef DEFINES_ZX_TEENSY_H
#define DEFINES_ZX_TEENSY_H

#define ZXTEENSY_VERSION "20261011"

#define ENABLE_BUILTIN_ROM_IF1
#define ENABLE_BUILTIN_ROM_MF128
//define ENABLE_BUILTIN_USB

//define DEBUG_OUTPUT
//define ENABLE_JOYSTICK_DEBUG

#define MAX_PATH 256

#define F_CSTR(string) ((const char*)F(string))

#define ESXMMC_BIN_PATH ((const char*)F("/ZXTEENSY/esxmmc.bin"))
#define MF128_ROM_PATH ((const char*)F("/ZXTEENSY/mf128.rom"))
#define GENIE128_ROM_PATH ((const char*)F("/ZXTEENSY/genie128.rom"))
#define LPRINT_ROM_PATH ((const char*)F("/ZXTEENSY/lprint32.rom"))
#define MODEM_ROM_PATH ((const char*)F("/ZXTEENSY/vtx.rom"))
#define IF1_ROM_PATH ((const char*)F("/ZXTEENSY/if1.rom"))
#define MENU_ROM_PATH ((const char*)F("/ZXTEENSY/menu.rom"))
#define MDR_EMULATOR_ROM_PATH ((const char*)F("/ZXTEENSY/SPECTRA_IF1_ED2_ME_ROM_Formatted.bin"))
#define ZXTEENSY_CFG_PATH ((const char*)F("/ZXTEENSY/ZXTEENSY.CFG"))
#define NETMAN_Z80_PATH ((const char*)F("/ZXTEENSY/netman.z80"))
#define RTC_SETUP_Z80_PATH ((const char*)F("/ZXTEENSY/rtc_setup.z80"))
#define STATE_ROOT_PATH ((const char*)F("/ZXTEENSY/STATE"))

#define STATE_SLOT_COUNT 16
#define STATE_POKE_SLOT (STATE_SLOT_COUNT - 1)

#define FWUPDATE_HEX_PATH "ZXTEENSY.HEX"
#define MODEM_URL_PATH ((const char*)F("\"glasstty.com\",6502"))

// Run the Teensy 4.1 with slight overclock at 720MHz
#define TEENSY_CLK_FREQ 720000000ULL

// Tick the SD and Serial at 7MHz
#define TICK_FREQ 7000000ULL
#define TICK_CYCCNT (TEENSY_CLK_FREQ / TICK_FREQ)

// Allow ~500ms for reset to debounce
#define TRIGGER_DELAY_MS 500
#define TRIGGER_DELAY_CNT ((TRIGGER_DELAY_MS * TEENSY_CLK_FREQ) / (TICK_CYCCNT * 1000))

// Allow ~125ms for button to debounce
#define BUTTON_DELAY_MS 125
#define BUTTON_DELAY_CNT ((BUTTON_DELAY_MS * TEENSY_CLK_FREQ) / (TICK_CYCCNT * 1000))

// If reset is held for an additional 2 seconds, then perform a hard reset
#define HARD_RESET_DELAY_MS 2000
#define HARD_RESET_DELAY_CNT ((HARD_RESET_DELAY_MS * TEENSY_CLK_FREQ) / (TICK_CYCCNT * 1000))

// ZXC3 flash erasure delay
#define ZXC3_ERASE_DELAY_MS 100
#define ZXC3_ERASE_DELAY_CNT ((ZXC3_ERASE_DELAY_MS * TEENSY_CLK_FREQ) / (TICK_CYCCNT * 1000))

// MLD flash erasure delay
#define MLD_ERASE_DELAY_MS 25
#define MLD_ERASE_DELAY_CNT ((MLD_ERASE_DELAY_MS * TEENSY_CLK_FREQ) / (TICK_CYCCNT * 1000))

// Tape T-state delay
#define TAPE_DELAY_CNT (TEENSY_CLK_FREQ / 3500000ULL)

// VTX5000 read data rate to 120 bps (~1200 baud)
#define MODEM_DELAY_CNT (TEENSY_CLK_FREQ / 120ULL)

// Maximum length of a visible file name
#define ROM_NAME_LEN 32

// Maximum length of ROM_NAME_LEN, tab and 2 x right icons
#define MENU_TXT_LEN (ROM_NAME_LEN + 3)

// Maximum length of menu entry
// NOTE: Allow for left icon, ROM_NAME_LEN, tab, 2 x right icons, and new-line
#define MENU_STR_LEN (ROM_NAME_LEN + 5)

#define PAGE_IN_ROM(bit) (romPaged |= (1UL << (bit)))
#define PAGE_OUT_ROM(bit) (romPaged &= ~(1UL << (bit)))
#define IS_ROM_PAGED(bit) ((romPaged >> (bit)) & 0x01)
#define IS_ROM_PRIORITY(bit) ((romPaged >= (1UL << (bit))))
#define IS_ROM_HIGHEST(bit) ((romPaged < (1UL << (bit + 1))))

#endif

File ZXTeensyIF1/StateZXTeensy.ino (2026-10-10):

#include <SD.h>
#include <SdFat.h>

// State files are standard, uncompressed Z80 v3 snapshots. This lets startup
// restoration reuse the existing snapshot loader and keeps the on-card format
// useful outside ZXTeensy.
static const uint32_t STATE_48_FILE_SIZE = 49248;
static const uint32_t STATE_128_FILE_SIZE = 131183;
static const size_t STATE_SCREEN_SIZE = 0x1B00;
static const uint8_t STATE_SIGNAL_FINISH = 0xC0;
static const uint16_t STATE_DEVICE_VERSION = 1;

typedef enum {
    STATE_FILE_STATE,
    STATE_FILE_SCREEN,
    STATE_FILE_DIVRAM,
    STATE_FILE_DIVEXT,
    STATE_FILE_MFRAM,
    STATE_FILE_DEVICE,
    MAX_STATE_FILE_COUNT
} state_file_t;

static const char* const PROGMEM STATE_FILE_NAMES[] = {
    "STATE.Z80", "SCREEN.SCR", "DIVRAM.BIN", "DIVEXT.BIN", "MFRAM.BIN",
    "DEVICE.BIN"
};

typedef struct __attribute__((packed)) {
    // Saved-record metadata.
    char magic[4];
    uint16_t version;
    uint16_t size;

    // Configuration normally loaded from ZXTEENSY.cfg.
    uint8_t divMmcPresent;
    uint8_t divMmcExtRamPresent;
    uint8_t divMmcRomPresent;
    uint8_t divMmcSdReadOnly;
    uint8_t interface1Present;
    uint8_t mf128Present;
    uint8_t uartPresent;
    uint8_t usbPresent;
    uint8_t gamepadButtons;
    uint8_t wifiNtpPresent;
    uint8_t wifiNtpTz;
    uint8_t dskPresent;
    uint8_t dskEnableDriveB;
    uint8_t modemPresent;
    uint8_t printerPresent;
    uint8_t lprintPresent;
    uint8_t bootIntoMenu;
    uint8_t menuEnableInGame;
    cfg_data_t cfgData;

    // Runtime device state.
    uint32_t romPaged;
    uint16_t romArrayPresent;
    uint8_t spectrumBankM;
    uint8_t spectrumBank678;
    uint8_t spectrumBorder;
    uint8_t rom1Paged;
    uint8_t rom23Paged;
    uint8_t interface1Enabled;
    uint8_t divMmcEnabled;
    uint8_t divMmcRomEnabled;
    uint8_t divMmcToggle;
    uint8_t divMmcAutoMap;
    uint8_t divMmcConMem;
    uint8_t divMmcMapRam;
    uint8_t divMmcRamBank;
    uint8_t divMmcExtRamEnabled;
    uint8_t divMmcAllRamPresent;
    uint8_t divMmcAllRam;
    uint8_t divMmcWriteLock;
    uint8_t divMmcMapDisable;
    uint8_t divMmcMapRamPage;
    uint8_t divMmcAllRamBankRom23;
    uint8_t divMmcAllRamBankRom01;
    uint8_t divMmcAllRamBankRom01Locked;
    uint8_t mf128Enabled;
    uint8_t mf128ActiveNMI;
    uint8_t mf128LoadGenie;
    uint8_t zxC2Present;
    uint8_t zxC3Present;
    uint8_t zxC2Lock;
    uint8_t zxC2ShadowRom;
    uint8_t zxC2RomBank;
    uint8_t zxC3Write;
    uint8_t zxC3FlashState;
    uint8_t zxC3FlashSetup;
    uint8_t mdrPresent;
    uint8_t mdrEnabled;
    uint8_t mdrMaxSector;
    char menuBrowserPath[MAX_PATH];
    uint8_t tzxPresent;
    uint8_t tzxEnabled;
    uint8_t dskEnabled;
    uint8_t printerEnabled;
    uint8_t lprintEnabled;
    uint8_t uartEnabled;
    uint8_t modemEnabled;
    uint8_t modemOnReset;
    uint8_t usbEnabled;
    uint8_t mousePresent;
    uint8_t joystickPresent;
    uint8_t printerStrobe;
    uint8_t printerByte;
    uint8_t divMmcSpiSdIdle;
    uint8_t divMmcHdfSdIdle;
    uint8_t divMmcSecondHdfSdIdle;
    uint32_t mouseX;
    uint32_t mouseY;
    uint32_t tapePosition;
    uint32_t tapeBufferPosition;
    uint32_t tapeFillPosition;
    uint32_t tapeBufferFillPosition;
    uint32_t tapeLength;
    uint8_t mldPresent;
    uint8_t mldSlotCount;
    uint8_t mldCmdLocked;
    uint8_t mldCmdDisabled;
    uint8_t mldCurrentSlot;
    uint8_t mldPreviousSlot;
} state_device_data_t;

File stateSaveFile;
volatile bool stateSaveActive = false;
volatile bool stateSaveActiveBlockPending = false;
volatile uint8_t stateSaveActiveBlock = 0;
bool stateSave128 = false;
uint8_t stateSaveExpectedBlock = 0;
uint8_t stateSaveActiveSlot = 0;
DMAMEM state_device_data_t stateRestoreDevice;
volatile bool stateLoadActive = false;
volatile bool stateLoadFinalStage = false;

uint16_t stateReadWord(const volatile uint8_t* data, uint16_t offset)
{
    return data[offset] | (data[offset + 1] << 8);
}

bool stateWriteBytes(const void* data, size_t size)
{
    return stateSaveFile && (stateSaveFile.write((const uint8_t*)data, size) == size);
}

uint8_t stateRegisterByte(uint16_t base, uint8_t offset)
{
    return menuRamArray[1][(base + offset) & (RAM_PAGE_SIZE - 1)];
}

uint32_t stateTestSimpleLz(uint8_t* fload, uint32_t filesize)
{
    uint32_t i = 1;
    uint32_t store_p = 2;
    int litsize = 1;
    uint32_t repsize, offset, repmax;
    do {
        // scan for sequence
        repmax = 2;
        if (i > 255) offset = i - 256; else offset = 0;
        do {
            repsize = 0;
            while ((i + repsize < filesize) && (repsize < 129) &&
                (fload[offset + repsize] == fload[i + repsize]))
            {
                repsize++;
            }
            if (repsize > repmax) {
                repmax = repsize;
            }
            offset++;
        } while ((offset < i) && (repmax < 129));
        if (repmax > 2) {
            if (litsize > 0) {
                store_p++;
                litsize = 0;
            }
            store_p += 2;
            i += repmax;
        }
        else {
            litsize++;
            store_p++;
            i++;
            if (litsize > 127) {
                store_p++;
                litsize = 0;
            }
        }
    } while (i < filesize);
    if (litsize > 0) {
        store_p++;
    }
    return store_p;
}
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

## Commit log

2026-01-24 feat: Initial PCB upload
    [1N4148.stp, CL1434 S6 nut.stp, DIP-40_W15.24mm.step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]
2026-01-24 feat: Upload initial PCB v0.3
    [Microdrive_IO.kicad_sch, Serial_IO.kicad_sch, ZXTeensyIF1.kicad_pcb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]
2026-01-24 feat: Add current status
2026-01-24 fix: missed KiCad library credit
2026-01-26 Fix Arduino folder name
    [ZXTeensyIF1.ino]
2026-01-27 Store Teensy pin assignment spreadsheet
    [teensy-pins.xlsx]
2026-01-27 feat: Tidy code, and debounce NMI button
2026-01-28 Preserve DivMMC RAM on reset
    [ZXTeensyIF1.ino]
2026-01-29 fix: Reset with DivMMC active did not detect SD card again
    [ZXTeensyIF1.ino]
2026-01-29 fix: Attempt to improve stability
    [ZXTeensyIF1.ino]
2026-01-31 fix: External ROMs use soft ROM too
    [ZXTeensyIF1.ino]
2026-02-01 fix: Spectrum ROMs reload after ZXC2 ROMs
    [ZXTeensyIF1.ino]
2026-02-02 fix: Initialise menu on reload
    [Menu.ino, ZXTeensyIF1.ino]
2026-02-05 feat: Add ESP-01S header to PCB v0.5
    [Microdrive_IO.kicad_sch, Serial_IO.kicad_sch, ZXTeensyIF1.kicad_pcb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]
2026-02-05 feat: Introduce hardware Serial8 as MB03+ UART
    [teensy-pins.xlsx]
2026-02-06 Refactor SPI and UART drivers
2026-02-06 Add UART to menu
2026-02-07 feat: Reimplement parts of HardwareSerialIMXRT into UartZXTeensy
2026-02-08 Add silkscreen text
    [ZXTeensyIF1.kicad_pcb]
2026-02-08 fix: ZXC2 banking on nWR
    [ZXTeensyIF1.ino]
2026-02-08 Disable interrupts on FW update
2026-02-13 Put spectrum into reset as early as possible
    [ZXTeensyIF1.ino]
2026-02-22 Use active DTR and TXDATA from MAX232
    [Serial_IO.kicad_sch, ZXTeensyIF1.kicad_pcb, teensy.kicad_sch]
2026-02-22 fix: Minor PCB tweak
    [ZXTeensyIF1.kicad_pcb]
2026-02-24 feat: Bridge DivMMC SPI to SDHC controller
2026-02-25 fix: Tidy up SDHC and menu code
    [ZXTeensyIF1.ino]
2026-02-25 feat: SDHC read using DMA
2026-02-25 fix: Allow warm reset of DivMMC, and fix ROMs across reset
    [Menu.ino, ZXTeensyIF1.ino]
2026-02-25 fix: Add faster SD card detect
    [ZXTeensyIF1.ino]
2026-02-25 fix: NMI to DivMMC
    [ZXTeensyIF1.ino]
2026-02-26 Disable DivMMC read DMA, add NMI tracing
2026-02-26 fix: DivMMC NMI crash due to RTC
    [ZXTeensyIF1.ino]
2026-02-27 feat: Hold reset to hard reset
    [ZXTeensyIF1.ino]
2026-03-02 fix: Attempt to start faster
    [ZXTeensyIF1.ino]
2026-03-02 fix: menu triggering FW update on browser open
    [Menu.ino, ZXTeensyIF1.ino]
2026-03-08 fix: Disable device, and re-enable on hard reset
    [ZXTeensyIF1.ino]
2026-03-08 fix: create configuration defaults correctly
    [Menu.ino]
2026-03-08 feat: Move SPI to SDHC bridge, to use SdFat SdioCard
2026-03-09 Move UART bridge back to using Serial8
2026-03-13 fix: ROM loading after reset
    [Menu.ino, ZXTeensyIF1.ino]
2026-03-16 feat: introduce lib765, fix off by one DSK issues
    [765dsk.c, 765fdc.c, ZXTeensyIF1.ino]
2026-03-18 feat: Add stored configs
    [128K ESXDOS.CFG, 48K IF1.CFG, ZX Spectrum +3.CFG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]
2026-03-19 Adjust UART buffer size
2026-03-19 fix: ESP-01S leaving transparent mode
    [UartZXTeensy.cpp, ZXTeensyIF1.ino]
2026-03-19 fix: UART read level indicator
2026-03-20 fix: TZX loading tweaks
    [ZXTeensyIF1.ino]
2026-03-20 Add CPU temperature status
2026-03-20 fix: UART after WiFi NTP
    [HttpZXTeensy.ino, Menu.ino, ZXTeensyIF1.ino]
2026-03-21 feat: Add debug menu, with USB buttons
2026-03-22 Add PCB v0.7 images
2026-03-23 Update configs, and ESXDOS ROM present
    [Micronet.CFG, ZX Spectrum +2.CFG, ZX Spectrum +2A.CFG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]
2026-03-23 Increase UART to hold 2 x MTU packets from +IPD
    [ZX Spectrum +3e.CFG]
2026-03-23 fix: Restrict VTX5000 data rate to 1200 baud
    [DefinesZXTeensy.h, UartZXTeensy.cpp]
2026-03-26 Revert UART status to the RingBuffer size
    [UartZXTeensy.cpp]
2026-03-29 fix: Typo in mask
    [DefinesZXTeensy.h, ZXTeensyIF1.ino]
2026-04-25 PCB move C6 slightly, C13 to 47uF
    [Serial_IO.kicad_sch, ZXTeensyIF1.csv, ZXTeensyIF1.kicad_pcb]
2026-04-25 Enable 4 buttons for gamepad
2026-05-01 fix: LPRINT III paging
    [DefinesZXTeensy.h, Menu.ino, ZXTeensyIF1.ino]
2026-05-01 Update configs
    [128K ESXDOS.CFG, Micronet.CFG, ZX Spectrum +2.CFG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]
2026-05-07 feat: Add in-game TZX and DSK swapping
    [DefinesZXTeensy.h, Menu.ino, ZXTeensyIF1.ino]
2026-05-18 Minor updates, add DivMMC 512KB option
    [128K ESXDOS.CFG, 128K LPRINT III.CFG, Micronet.CFG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]
2026-05-22 fix: NMI into menu from MF128
    [DefinesZXTeensy.h, Menu.ino, ZXTeensyIF1.ino]
2026-05-25 fix: Split SD buffers to per device, and fix resets
    [DefinesZXTeensy.h, SdHdfZXTeensy.h, ZXTeensyIF1.ino]
2026-06-01 fix: Improve menu stability
    [DefinesZXTeensy.h, Menu.ino, ZXTeensyIF1.ino]
2026-06-06 fix: odd UART menu stability
    [DefinesZXTeensy.h, ZXTeensyIF1.ino]
2026-06-06 fix: Missed UART buffer clear
    [ZXTeensyIF1.ino]
2026-06-27 fix: Save/restore AY registers for in-game menu
    [Menu.ino]
2026-06-28 fix: Fix saved state as 48K with Internal ROM
    [Menu.ino, StateZXTeensy.ino, ZXTeensyIF1.ino]
2026-06-28 fix: Save and restore more state
    [Menu.ino, SdHdfZXTeensy.h, StateZXTeensy.ino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]
2026-06-30 fix: Configuration and save slot on restore
    [Menu.ino, StateZXTeensy.ino, ZXTeensyIF1.ino]
2026-07-01 fix: Restore ROM banking on final page out
    [DefinesZXTeensy.h, StateZXTeensy.ino, ZXTeensyIF1.ino]
2026-07-01 fix: Restore state when SP is in peripheral RAM
    [Menu.ino, ZXTeensyIF1.ino]
2026-07-02 Add some load/save failed messaging
    [DefinesZXTeensy.h, HttpZXTeensy.ino, Menu.ino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]
2026-07-03 fix: Additional menu limits
    [DefinesZXTeensy.h, Menu.ino]
2026-07-03 Add NXtel config
    [NXtel.CFG]
2026-07-05 fix: Improvements to POKEs
    [PokZXTeensy.ino, StateZXTeensy.ino, ZXTeensyIF1.ino]
2026-07-06 fix: Detect BASIC tape header in TZX turbo blocks
    [DefinesZXTeensy.h]
2026-07-09 Store additional materials
    [128K ESXDOS.CFG, 128K LPRINT III.CFG, Micronet.CFG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]
2026-07-09 Add current firmware image
2026-07-09 fix: Large TZX files load in circular buffer
    [DefinesZXTeensy.h, Menu.ino, StateZXTeensy.ino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]
2026-07-10 fix: HDF image card size truncation
    [SdHdfZXTeensy.h]
2026-07-10 feat: Improve DivMMC drive configuration
    [128K ESXDOS.CFG, ZX Spectrum +3e.CFG, ZXTeensyIF1.CFG]
2026-07-11 feat: More menu improvements, speed to 720MHz
    [128K ESXDOS.CFG, 128K LPRINT III.CFG, ZX Spectrum +2.CFG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]
2026-07-11 fix: Allow long POKE names
    [PokZXTeensy.ino]
2026-07-11 fix: Tape after state restore
    [StateZXTeensy.ino]
2026-07-11 fix: Reduce directory scanning in large directories
    [Menu.ino]
2026-07-11 fix: Avoid storing previous entries for large directories
    [Menu.ino]
2026-07-13 fix: Non-browser file listings in menu
    [Menu.ino]
2026-07-17 feat: Printer output is now timestamped
2026-07-17 Add printer to PDF tool, via Codex
2026-07-18 feat: Write disk when motor stops, and improve messaging
2026-07-18 fix: HTTP server GET bytes count
    [HttpZXTeensy.ino]
2026-07-19 fix: Move to in-game printer new document
    [DefinesZXTeensy.h, Menu.ino]
2026-07-19 feat: Preserve Wifi NTP settings on restore
    [128K ESXDOS.CFG, 128K LPRINT III.CFG, Micronet.CFG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]
2026-07-19 fix: DivMMC ROM automapping tweak
    [ZXTeensyIF1.ino]
2026-07-22 fix: Dandanator flash writes, and slow pulse commands
    [ZXTeensyIF1.ino]
2026-07-23 fix: initial Centronics strobe
    [DefinesZXTeensy.h, ZXTeensyIF1.ino]
2026-07-23 fix: ZXC3/MDR/MLD save path on state restore
    [DefinesZXTeensy.h, Menu.ino, StateZXTeensy.ino]
2026-07-26 fix: SD card file timestamps
    [ZXTeensyIF1.ino]
2026-07-27 fix: More loose ends
    [DefinesZXTeensy.h, HttpZXTeensy.ino, Menu.ino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]
2026-07-30 fix: TZX add set level block
    [DefinesZXTeensy.h]
2026-07-30 fix: Flash status indicator per sector
    [ZXTeensyIF1.ino]
2026-07-31 fix: Flash erase sectors concurrently
    [ZXTeensyIF1.ino]
2026-07-31 fix: Save state against MLD
    [StateZXTeensy.ino, ZXTeensyIF1.ino]
2026-08-01 fix: MLD pulse commands need fast paging
    [DefinesZXTeensy.h, ZXTeensyIF1.ino]
2026-08-29 feat: Add more build details
    [ZXTeensyIF1.kicad_pcb]
2026-09-20 fix: Improve ISR compatibility
    [DefinesZXTeensy.h, ZXTeensyIF1.ino]
2026-10-03 fix: Menu ROM inhibits Interface 1
    [DefinesZXTeensy.h, ZXTeensyIF1.ino]
2026-10-04 feat: Reduce and fix reset timings
    [DefinesZXTeensy.h, ZXTeensyIF1.ino]
2026-10-04 fix: Try to read keys whilst driving tape
    [ZXTeensyIF1.ino]
2026-10-07 fix: Reset ESP-01S on regular reset
    [DefinesZXTeensy.h, HttpZXTeensy.ino, UartZXTeensy.cpp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]
2026-10-10 fix: Indicate HTTP server error
    [HttpZXTeensy.ino]
2026-10-10 fix: Optimise to recover ITCM RAM1 space
    [Menu.ino, StateZXTeensy.ino, ZXTeensyIF1.ino]
2026-10-10 fix: Built-in ROMs not going to PROGMEM, via Codex
    [DefinesZXTeensy.h, ZXTeensyIF1.ino]
2026-10-10 fix: Enable built-in Multiface 128
    [Menu.ino]
2026-10-10 fix: Multiface 128 repeated NMI entry
    [ZXTeensyIF1.ino]
2026-10-10 fix: ISR capturing bus activity during reset
    [DefinesZXTeensy.h, ZXTeensyIF1.ino]
2026-10-11 feat: Add eLeMeNt ZX UART registers support
2026-11-01 fix: Sample beeper for HDMI audio
2026-11-08 fix: Sample and average beeper sound for HDMI

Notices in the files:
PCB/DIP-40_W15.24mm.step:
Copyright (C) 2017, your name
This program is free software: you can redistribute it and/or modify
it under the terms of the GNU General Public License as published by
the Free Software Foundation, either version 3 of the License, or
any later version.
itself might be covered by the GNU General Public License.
